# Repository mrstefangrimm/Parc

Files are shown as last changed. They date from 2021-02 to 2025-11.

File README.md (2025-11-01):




# Parc
Parc stand for Programmable Arduino Remote Control. This repository contains the software, the hardware and the mechanical design files.

| Parc (original) | Parc (PCB) |
| --- | --- |
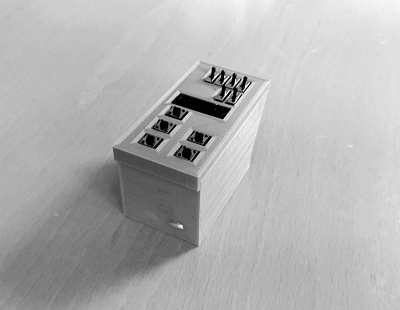
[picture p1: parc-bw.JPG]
Parc
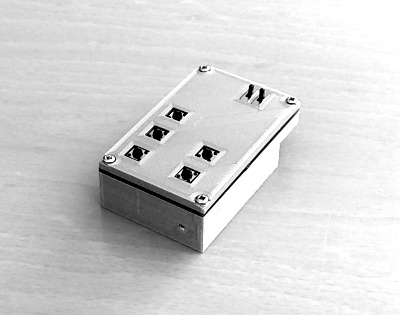
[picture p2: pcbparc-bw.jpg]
PCB Parc
|  |  |

## Motivation

One way to automated tasks on your PC is to write scripts. To run a script you have to be logged in to your PC already. If you write a script to lets say  sign in on a web application, it is not very save to put the password directly into the script.

Parc is a microcontroller based device that acts as a HID, these problems are solved.

## Getting Started

To use the software, you will have to build a Parc device. How to build one is described in an [instructable](https://www.instructables.com/Programmable-Arduino-Remote-Control/).

The software is very flexible and it is also possible to use it together with a breadboard or an Arduino UNO.

Minimal requirements to use the software on a breadboard:

- Arduino IDE
- Adafruit feather 32u4 BLE or Arduino UNO
- MCP23008
- Breadboard
- Push buttons and toggle switches

## Examples

A user manual and a programming guide can be found in the [Parc Wiki](https://github.com/mrstefangrimm/Parc/wiki).

## Tests

Unit tests cover the functionality of the domain model classes. All unit tests are part of the WinParcApp Visual Studio solution. Some test are can be executed with ArduinoUnit too.

Manual tests are defined in the [Test Specification](https://github.com/mrstefangrimm/Parc/blob/main/BuildVerificationTest-Specification.md).

## Software Toolchain

**Built Applications**

| Application | License |
| --- | --- |
| ParcApp | LGPL |
| PcbParcApp  | LGPL |
| UnoParcApp  | LGPL |
| WinParcApp  | LGPL |

**Used Libraries**

| Library | Licence |
| :--- | --- |
| ParcLib | LGPL |
| Adafruit MCP23017 Arduino Library | BSD |
| Adafruit BluefruitLE nRF51 | BSD |
| Arduino.h | LGPL |
| ArduinoUnit | MIT |
| StandardCplusplus | LGPL |
| TimerOne | CC BY 3.0 US |
| TemplateStateMachine | Apache License |
| .NET 4.8.1 | Microsoft license |

**Used Software Development Tools**

| Tool | License |
| --- | --- |
| Arduino IDE | GPL |
| Adafruit AVR Boards [Learn more](https://learn.adafruit.com/adafruit-feather-32u4-bluefruit-le/setup) | Adafruit license |
| avrdude | GPL |
| gcc | GPL |
| Visual Studio Community 2022 | Microsoft license |

## License

This is free software: you can redistribute it and/or modify it under the terms of the GNU Lesser General Public License as published by the Free Software Foundation, either version 3 of the License, or (at your option) any later version.

## Project History

The idea for the project came in mid January 2021 and was first published on instructables.com in mid April 2021.

## Change History

See [github releases](https://github.com/mrstefangrimm/Parc/releases).

<br />This work is licensed under a <a rel="license" href="http://creativecommons.org/licenses/by-sa/4.0/">Creative Commons Attribution-ShareAlike 4.0 International License</a>.

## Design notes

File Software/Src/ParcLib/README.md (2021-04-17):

# ParcLib

Arduino library which is part of the Parc software package. The library contains the domain model and shared code for 32u4 feathers. All Parc device projects are based on this library.

See also the [Parc Readme](https://github.com/mrstefangrimm/parc/) for a more detailed Readme.

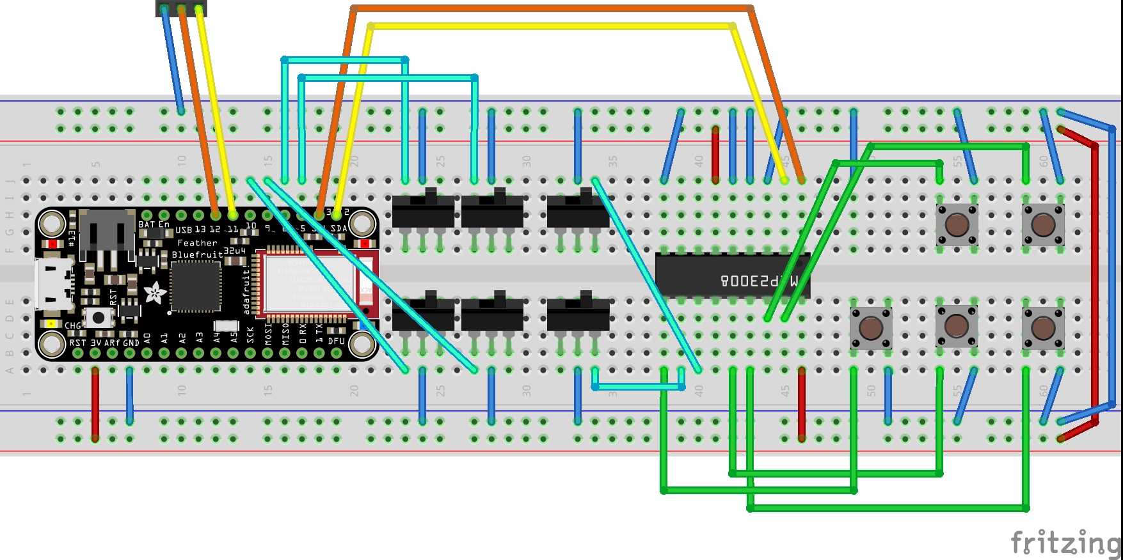
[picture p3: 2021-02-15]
Hardware/Fritzing/Breadboard-Parc.jpg

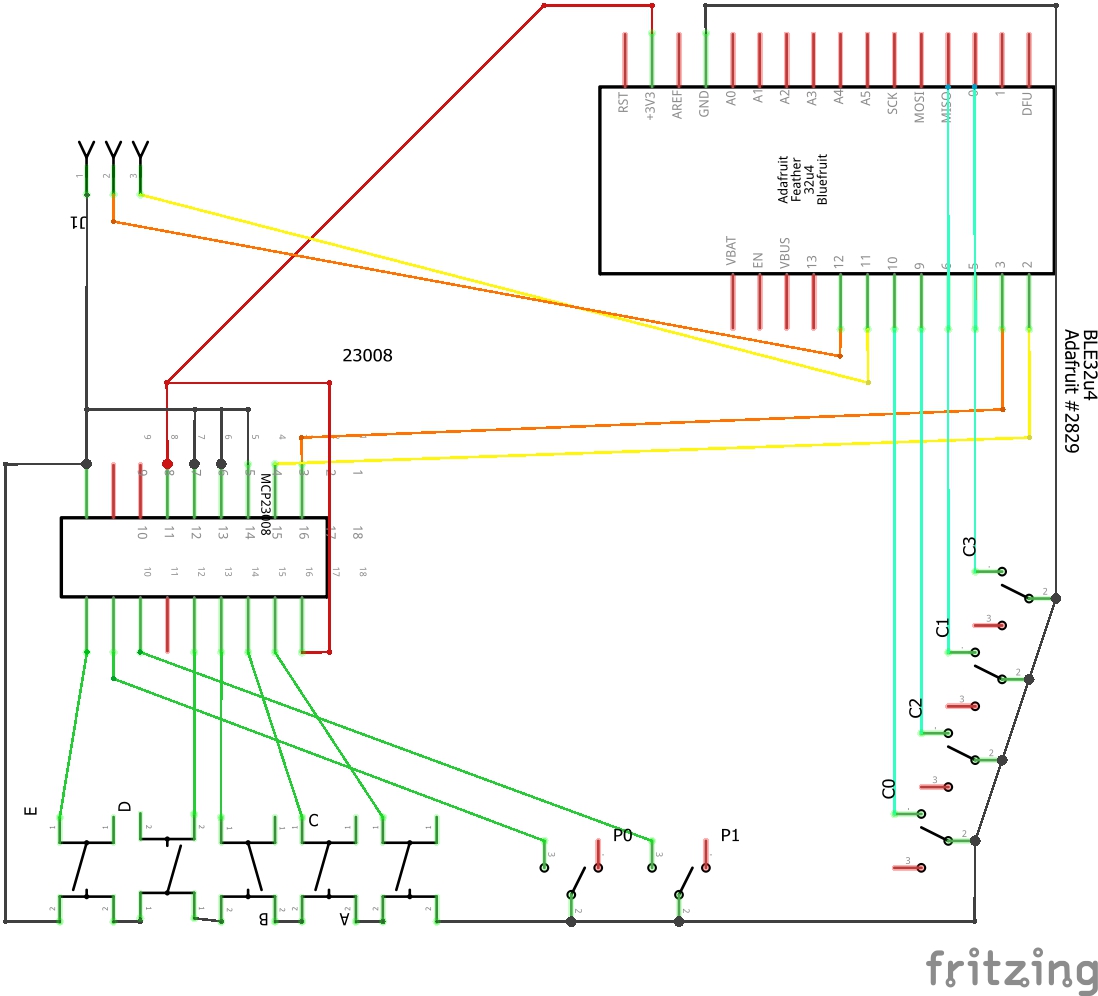
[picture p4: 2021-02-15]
Hardware/Fritzing/Schematic-Parc.jpg

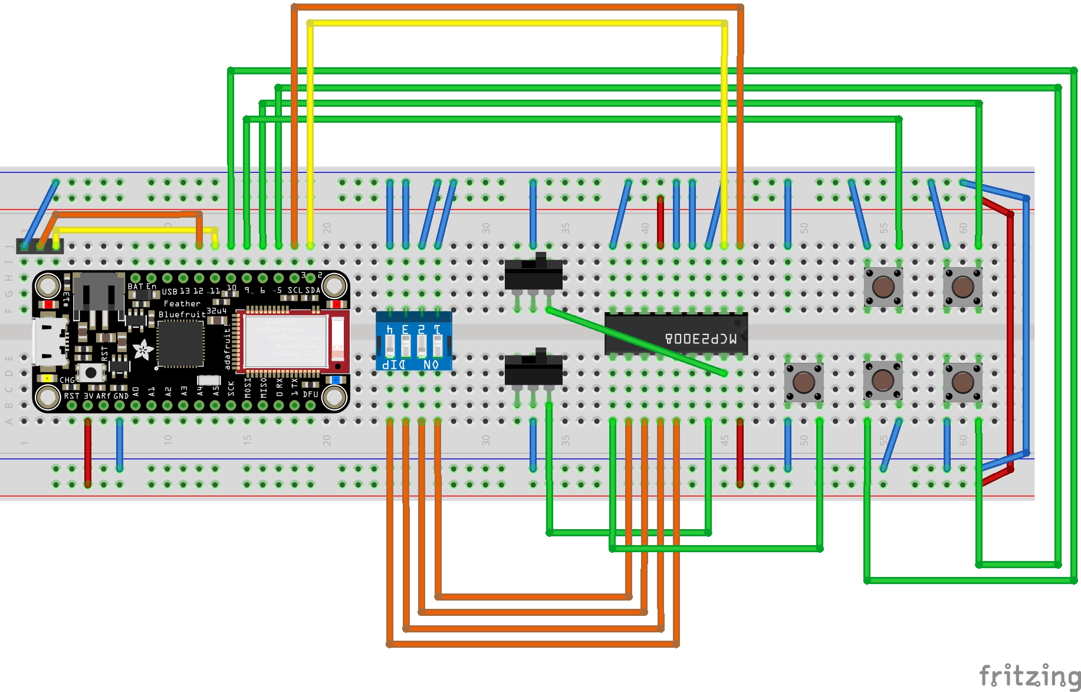
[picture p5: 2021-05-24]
Hardware/Fritzing/Breadboard-PcbParc.jpg

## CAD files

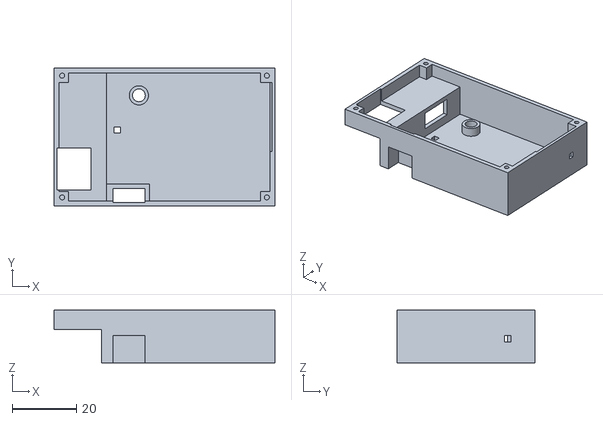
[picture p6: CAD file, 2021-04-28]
Instructable/STL-Models/PcbParc-Case.stl
69.0 x 43.0 x 16.5

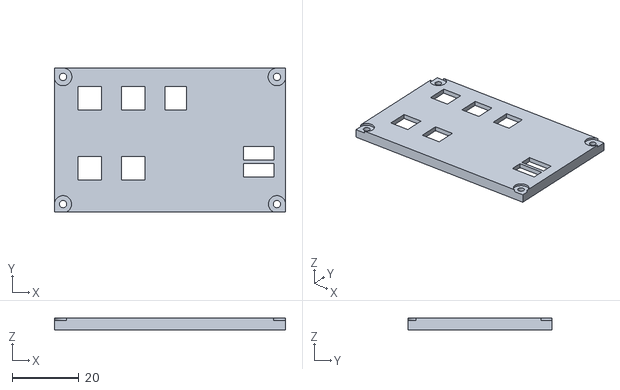
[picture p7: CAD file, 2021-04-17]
Instructable/STL-Models/PcbParc-Top.stl
69.0 x 43.0 x 3.50

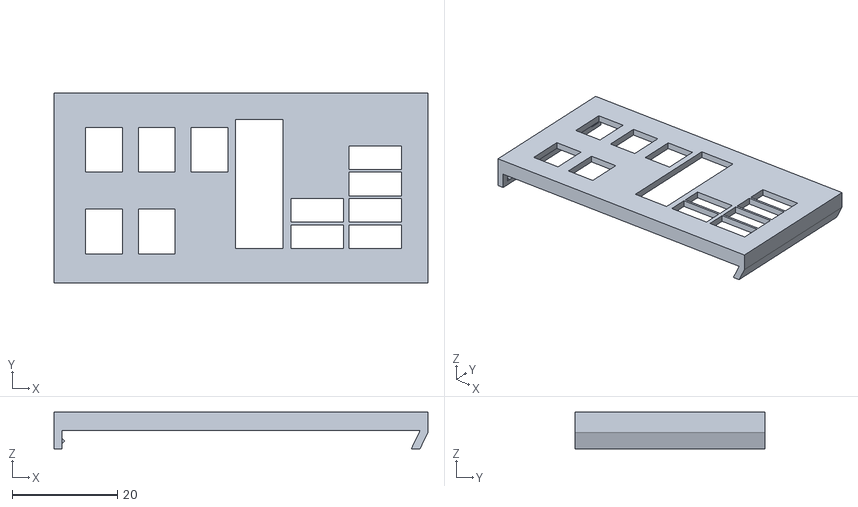
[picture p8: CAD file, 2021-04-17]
Instructable/STL-Models/Parc-Top.stl
71.0 x 36.0 x 7.00

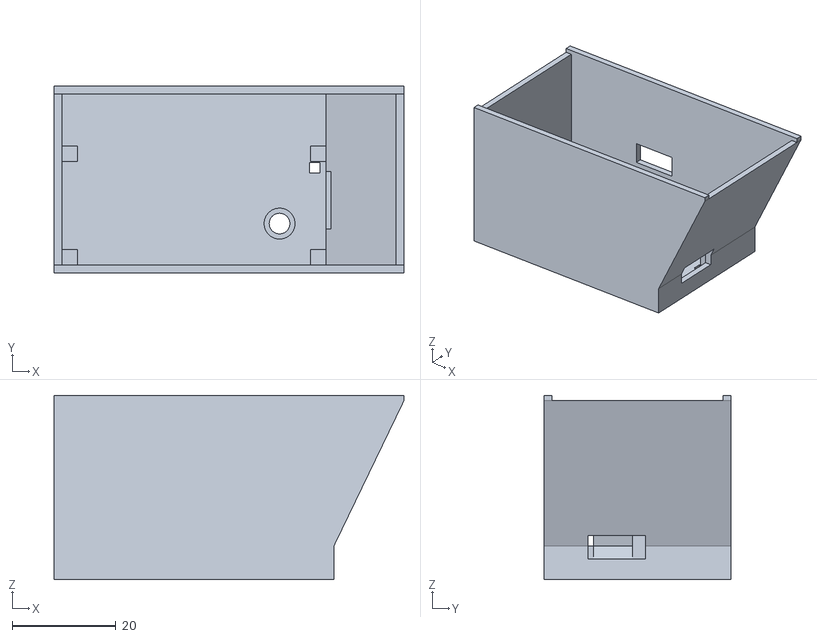
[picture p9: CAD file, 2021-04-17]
Instructable/STL-Models/Parc-Case.stl
67.5 x 36.0 x 35.5

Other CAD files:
MechanicalDesign/Sketchup/Parc-Case.skp
MechanicalDesign/Sketchup/Parc-Top.skp
MechanicalDesign/Sketchup/Parc-Total.skp
MechanicalDesign/Sketchup/PcbParc-Case.skp
MechanicalDesign/Sketchup/PcbParc-Shield.skp
MechanicalDesign/Sketchup/PcbParc-Top.skp

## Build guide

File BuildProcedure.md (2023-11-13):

# Parc Software Build Procedure

The build steps to build the Parc simulator and the PCB production files.

## 0. Preparation

Required software:

- Microsoft Visual Studio 2022
- Fitzing

Create a package folder.

## 1. Build Simulator

1. In Visual Studio, open 'WinParcApp.sln' from '\Software\Src\WinParcApp' with administrator rights.
2. Set 'WinParc.App' as startup project
3. Set the build configuration to 'Release' and 'x86'
4. Build the solution
5. Copy these file from the folder '\Software\Src\WinParcApp\Release' to a folder ' package\Software\Simulator':
   - WinParc.App.exe
   - WinParc.APIWrapper.dll
   - WinParcAPI.dll
   - WinParc.Core.dll
   - WinParc.View.exe

## 2. Create PCB Gerber files 

1. In Fritzing, open 'Keypad-v2.fzz'
2. Create folder 'Keypad-v2-Gerber'
3. File, Export, for Production, Extended Gerber (RS-274x)
4. Compress the folder to 'Keypad-v2-Gerber.zip'
5. Copy the files 'Keypad-v2.fzz' and 'Keypad-v2-Gerber.zip' to the folder 'package\Hardware'

## 3. Copy projects

1. Copy the 'ParcLib' folder from '\Software\Src' to the package folder
2. Copy the 'ParcApp' folder from '\Software\Src' to the package folder
3. Copy the 'PcbParcApp' folder from '\Software\Src' to the package folder
4. Copy the 'UnoParcApp' folder from '\Software\Src' to the package folder
5. In all folders form above, remove the file `PreBuild.bat`
6. In all the folders form above,  remove the links to the folders 'Core' and 'Feather' (don't forget the Test-folders in the ParcLib)

## 4. Create ParcLib Arduino library

1. Check the version in Software\ParcLib\library.properties
2.  Zip the folder ParcLib to ParcLib.zip (the root folder of ParcLib.zip is ParcLib; that is correct.)

## 5. Finalize the package

Package structure:

package_v0_0_1_0.zip/

	/Software/Simulator/*

	/Software/ParcLib.zip

	/Software/ParcApp/*

	/Software/PcbParcApp/*

	/Software/UnoParcApp/*

	/Hardware/Keypad-v2-Gerber.zip

	/Hardware/Keypad-v2.fzz

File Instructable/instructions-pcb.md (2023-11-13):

# Programmable Arduino Remote Control (PCB)

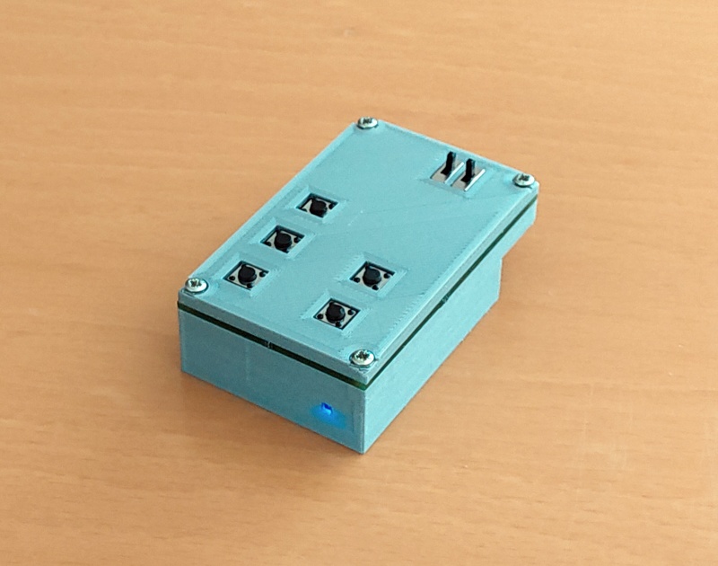
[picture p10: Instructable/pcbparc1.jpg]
parc1


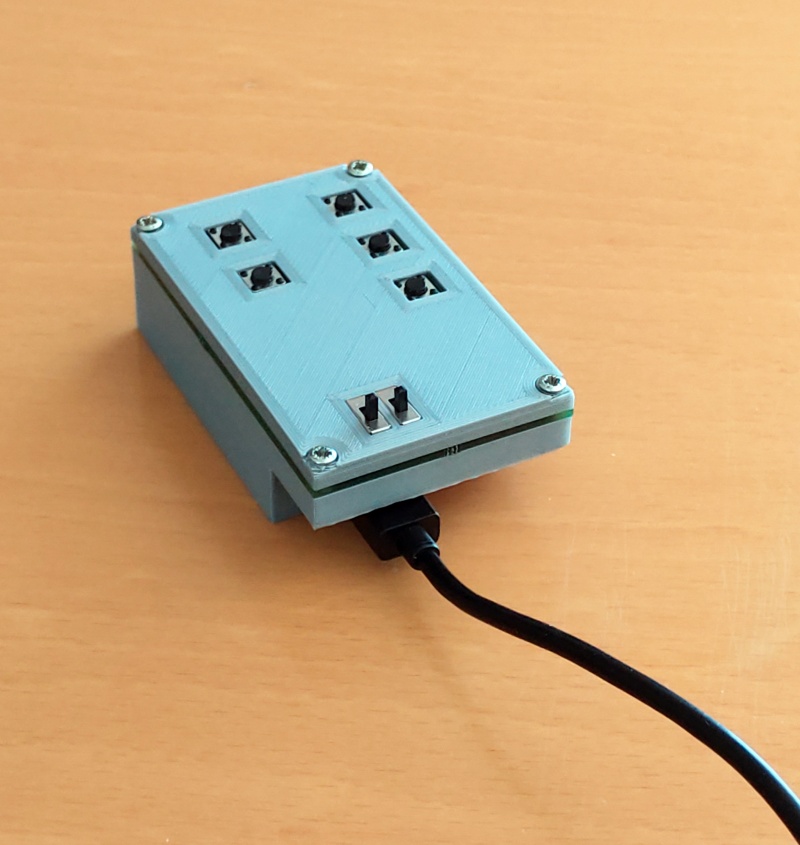
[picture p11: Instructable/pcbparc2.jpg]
parc2


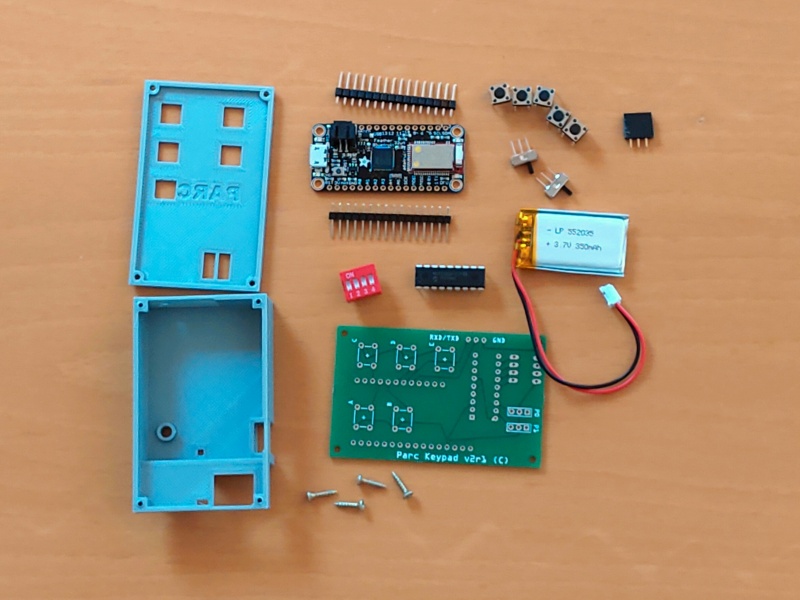
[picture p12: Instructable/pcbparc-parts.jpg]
parts


With this small, palm-sized device, it is possible to remote control your PC or your Smartphone. Or to control your PC and your Smartphone at the same time.

And it is freely programmable. You can write programs like: Login to  your PC, open and login to instructables.com, play/pause a movie or  adjust the volume on your Smartphone.

How is that possible? The used micro controller board has a chip that can act as a so called HID device, which stands for Human Interaction Device and simply means keyboard or mouse. And it has another chip, a Bluetooth chip which can act as a Bluetooth keyboard.

The programming is intuitive and there are more examples in the User Manual in the Wiki [1]. The syntax is described in the Programming Guide [1]. The video demonstrates a wireless login to a Windows PC with one click and a login to instructables.com with another click.

https://youtu.be/EJmvuccJp7M

What makes this remote control unique is that everything is stored in the volatile memory of the micro controller. It is safe to write programs which contain passwords.

And it is unique as Bluetooth remote control which you can program from a long list of possible commands. For more details see also the User Manual [1].

This is a improved version of the [Programmable Arduino Remote Control](https://www.instructables.com/Programmable-Arduino-Remote-Control/). It uses a printed circuit board (PCB) which you have to have manufactured. This costs a little extra. In return, the shape is more that of a remote control and it requires less soldering.

In this project, my goal  was to make a device that looks more like a remote control. Further, and because I use it every day, I wanted something more robust than its predecessor.

The direct material costs are approximately USD 78.

[1] [Parc Wiki on github](https://github.com/mrstefangrimm/Parc/wiki)

### Supplies:

1 Adafruit Feather 32u4 Ble ([at adafruit.com](https://www.adafruit.com/product/2829))

1 MicroUSB cable

1 Custom PCB (see step Printed Circuit Board)

1 IC MCP23008 (https://www.adafruit.com/product/593)

1 LiPo 350 mAh (https://www.adafruit.com/product/2750)

5 Button switch, 6mm (https://www.adafruit.com/product/1119)

2 Slide switch (https://www.adafruit.com/product/805)

1 Stack female headers (https://www.adafruit.com/product/2886)

1 DIP switch 4 positions ([at mouser](https://www.mouser.com/ProductDetail/E-Switch/KAS1104ET?qs=f57gQzlyLioBdQLVanmY3g%3D%3D))

4 Screw M2 x l10

1 Windows PC

1 Arduino IDE (https://www.arduino.cc/en/software). Optional: PuTTY (https://www.putty.org)

1 3D Printer

1 Soldering iron and soldering wire

21g PLA filament

I added links to the Adafruit and the Mouser web shops, but you also get the parts elsewhere. For example for the LiPo battery, search for "PKCELL LP552035".

## Step 1: 3D printed parts

PLA and the standard settings (20% infill) can be used. Support structures have to be enabled.

- PcbParc-Case.stl

- PcbParc-Top.stl

## Step 2: Printed Circuit Board

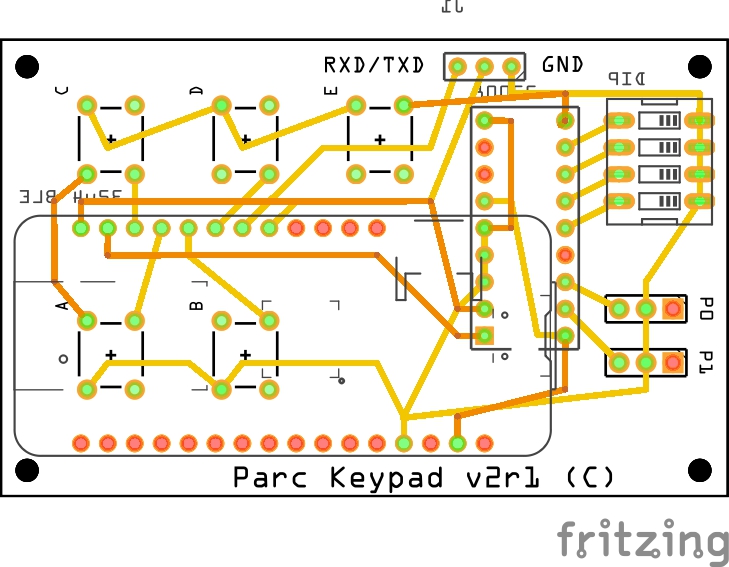
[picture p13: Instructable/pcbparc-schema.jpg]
PCB Schema


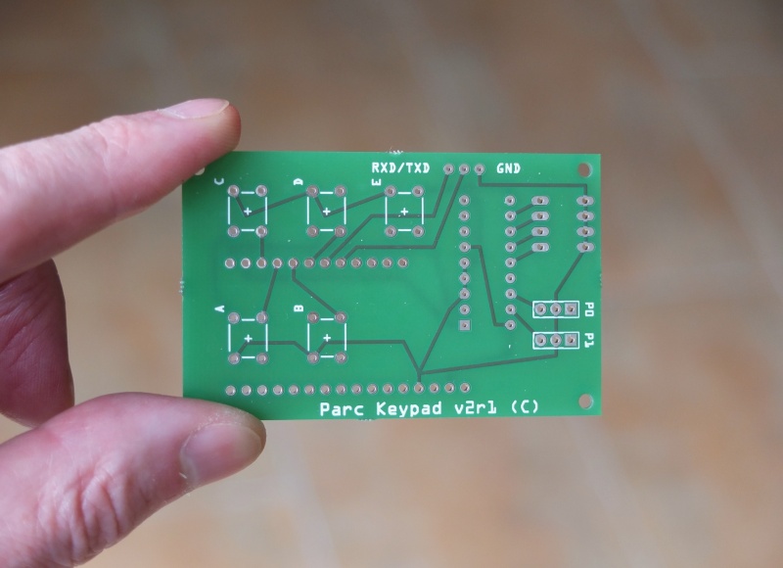
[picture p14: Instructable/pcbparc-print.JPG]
PCB Print


I had mine produced by Aisler (https://aisler.net/). At Aisler, it is possible to produce the PCB directly from the attached Fritzing project file.

If the manufacturer of your choice does not support Fritzing as import format, then try the [Gerber files](https://github.com/mrstefangrimm/Parc/blob/main/Instructable/Keypad-v2-Gerber.zip). "All" manufacturer support Gerbers.

## Step 3: Soldering keypad

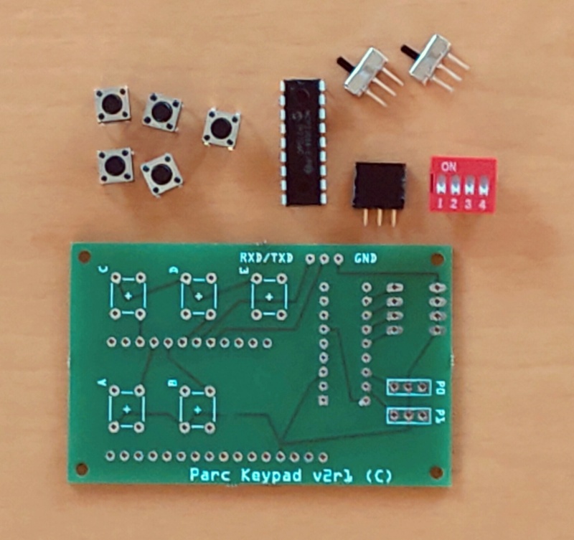
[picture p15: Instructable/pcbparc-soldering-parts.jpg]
soldering parts


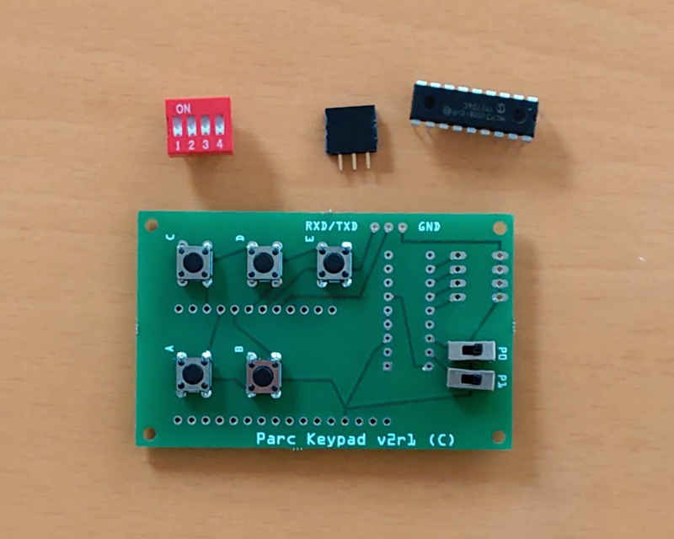
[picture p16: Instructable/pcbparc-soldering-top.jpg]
soldering keypad-top


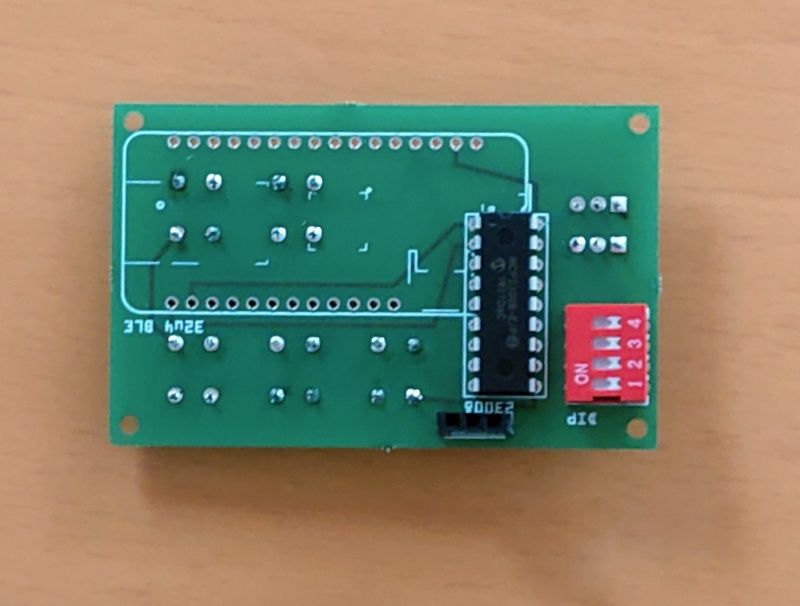
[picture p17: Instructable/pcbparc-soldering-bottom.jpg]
soldering keypad-bottom


Solder the five push buttons and the two slide switches to the front side of the PCB. Turn the PCB and add the MCP23008. Make sure the direction of the IC is correct.

Add the DIP switch.

From a female header stack, break out a piece of three pin sockets. Solder this piece to the back side of the PCB. 

## Step 4: Soldering micro controller

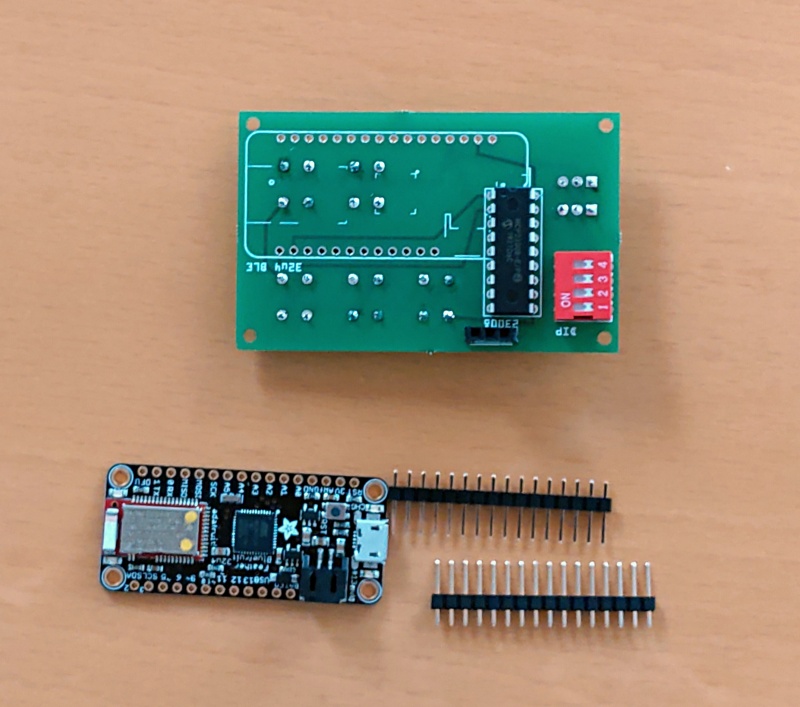
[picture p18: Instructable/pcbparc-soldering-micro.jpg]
soldering keypad-bottom


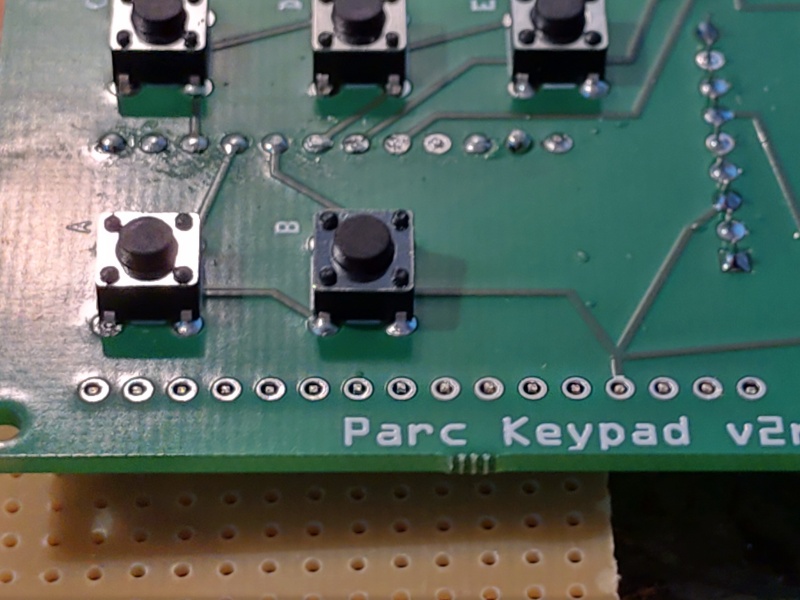
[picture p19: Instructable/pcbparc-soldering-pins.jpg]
soldering keypad-microcontroller


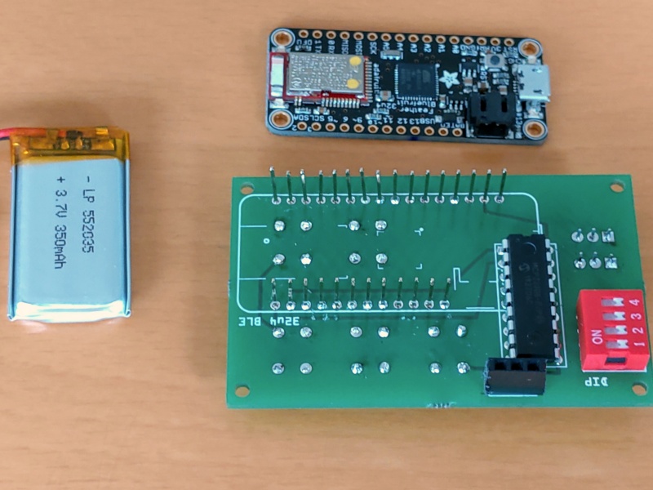
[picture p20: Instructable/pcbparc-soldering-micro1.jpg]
soldering keypad-microcontroller


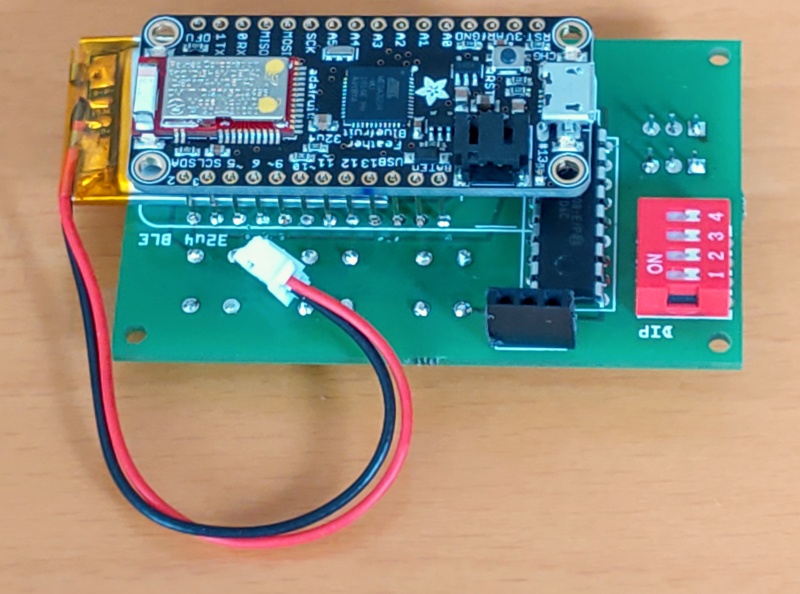
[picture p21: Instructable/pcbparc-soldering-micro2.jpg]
soldering keypad-microcontroller


Solder the header pins to the back side of the keypad. You can also solder the pins first to the micro controller board and as the second solder it to the keypad.

Solder the pins flush to the keypad. The plastic distance holder that holds the pins as an array is by default set that the pins look out 1 mm. So you have to push the pins 1 mm down first.

After the pins are soldered to the keypad, remove the black distance holder band. The battery will required all the space in between the two components.

Lastly, add the micro controller board. The battery shall be free movable between the two components.

## Step 5: Assemble

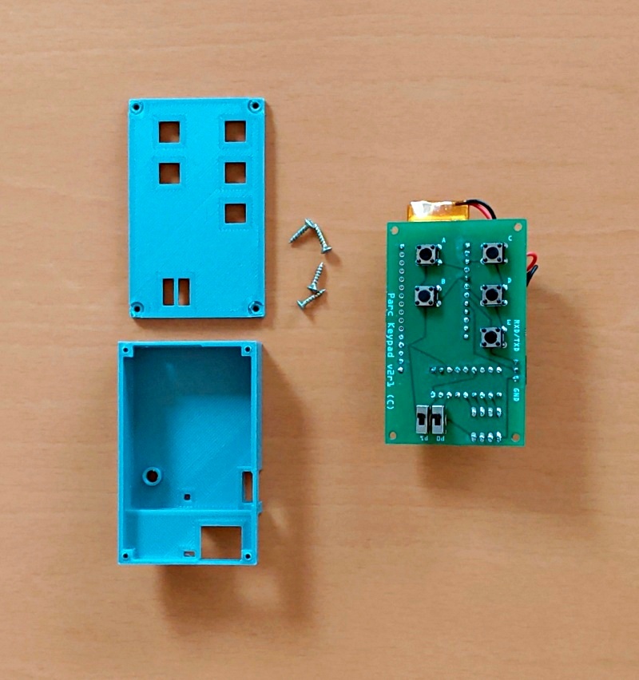
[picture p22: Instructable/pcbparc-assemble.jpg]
assemble


Connect the battery to the micro controller board. Now you can put whole assembly into the case and use it.

That was it basically. Next you will learn how to install the software and program the remote control.

## Step 6: Arduino IDE, libraries and boards

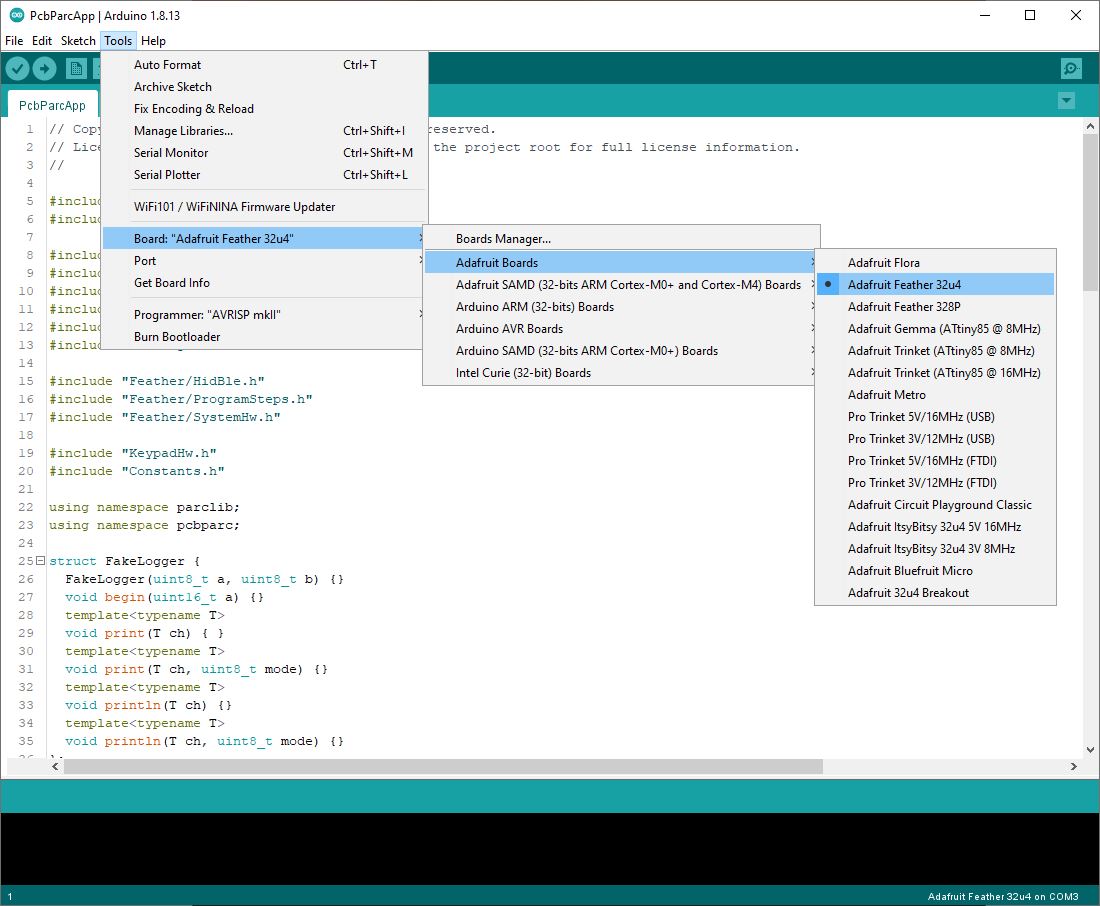
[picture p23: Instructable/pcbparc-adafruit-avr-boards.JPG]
Adafruit Boards


For the following steps, the [Arduino IDE](https://www.arduino.cc/en/software) is required. Download and install the IDE.

Follow the steps from Adafruit and install the "Adafruit AVR Boards" board package. Adafruit has always great [step-by-step instructions](https://learn.adafruit.com/adafruit-feather-32u4-bluefruit-le/setup).

In the Arduino IDE library manager, install the libraries "Adafruit MCP23008 library" and "TimerOne".

Download the  [Template State Machine library](https://github.com/mrstefangrimm/TemplateStateMachine/releases) and [import the .zip file](https://docs.arduino.cc/software/ide-v1/tutorials/installing-libraries#importing-a-zip-library) in the Arduino IDE.

Download the latestes [packages_v0.1.x.x.zip version from releases](https://github.com/mrstefangrimm/Parc/releases). Unzip the package folder and [import the Parclib.zip](https://docs.arduino.cc/software/ide-v1/tutorials/installing-libraries#importing-a-zip-library) in the Arduino IDE.

Copy PcbParcApp in the package folder into your project folder and open the PcbParcApp.ino in the  Arduino IDE.

Attach the PCB Parc remote control to your PC with the USB cable. In the  IDE, select the board "Adafruit Feather 32u4" and select the COM port with the same label.

If compiling and uploading succeeds, your device is ready for use.

## Step 7: Test software

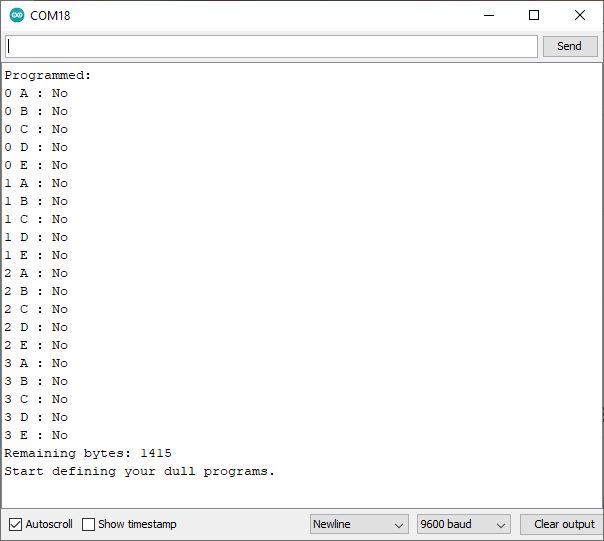
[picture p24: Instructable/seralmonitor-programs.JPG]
Serial Monitor


Open the PcbParcApp.ino in the Arduino IDE. Compile and upload the software.

In the Arduino IDE, open the Serial Monitor. In the input field, type in a question mark ("?") and hit "Send". As you haven't programmed your device yet, all program slots are empty.

Here's your first program. In the input field of the Serial Monitor, type in: "{ 0 B: UK <Win> 'l'; }" and press "Send". The left lower button on the keypad will now lock the Windows screen when pressed.

## Step 8: Program

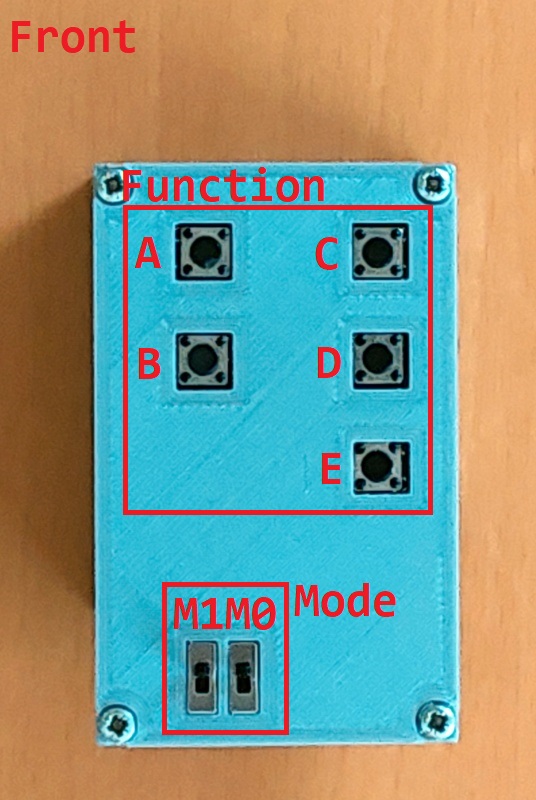
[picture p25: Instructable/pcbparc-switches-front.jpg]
Parc keypad


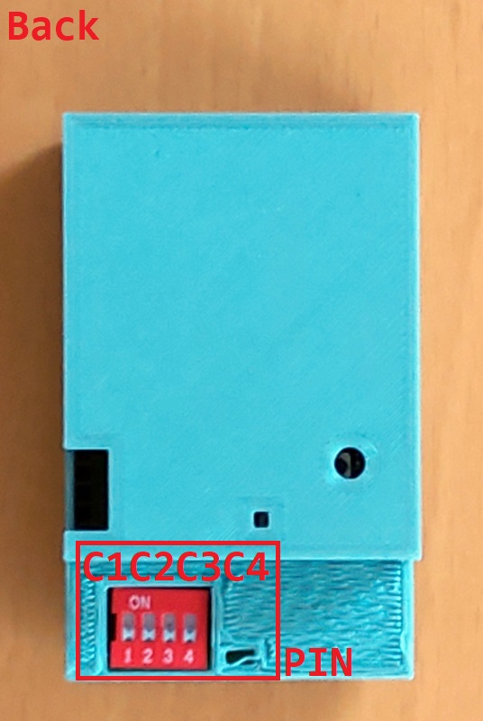
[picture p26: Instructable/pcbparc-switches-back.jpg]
Parc keypad


It is time to code. To give you an idea, I describe some of the programs used in the demo videos linked in the introduction section. For More information, please have a look at the User Manual in the [Wiki](https://github.com/mrstefangrimm/Parc/wiki).

Login Commands:

`{ 1 A: BK <Ctrl> <Alt> <Del>; W 2000; BT password; W 1000; BK <Enter>; }`

- "1 A" defines the key and mode the program is for. "1" is mode 1 which is  set with the slide switch M0. "A" is the upper left button
- `BK <Ctrl> <Alt> <Del>` sends a "Del" keypress with the control keys "Ctrl" and "Alt"
- "W 2000" lets the program wait for 2 seconds. The program waits for the Windows login screen before it writes the password
- "BT password" sends keypresses "p", "a", "s", ... . Note that it assumes a US-English keyboard. If you have keyboard settings for a different keyboard, there is a simple trick: Send `BK <Win> <Space>` as the first program step. This will change the keyboard on the PC.

Remote Control Commands:

```{ 3 A: BC PlayPause; }
{ 3 B: BC MediaNext; }
{ 3 C: BC Volume+; }
{ 3 D: BC Volume-; }
{ 3 E: BC Mute 1000; }
```

- "3 A" defines the program for mode 3 and key "A". Mode 3 is set with the slide switches "M1" and "M0"
- "BC" stands for Bluetooth Controlkey. This sends commands that most Bluetooth connected devices "understand"
- "BC Mute 1000". Sends Mute and waits for 1 second. This seconds hinders the device to interpret you key press as two keypresses

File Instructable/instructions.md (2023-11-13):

# Programmable Arduino Remote Control

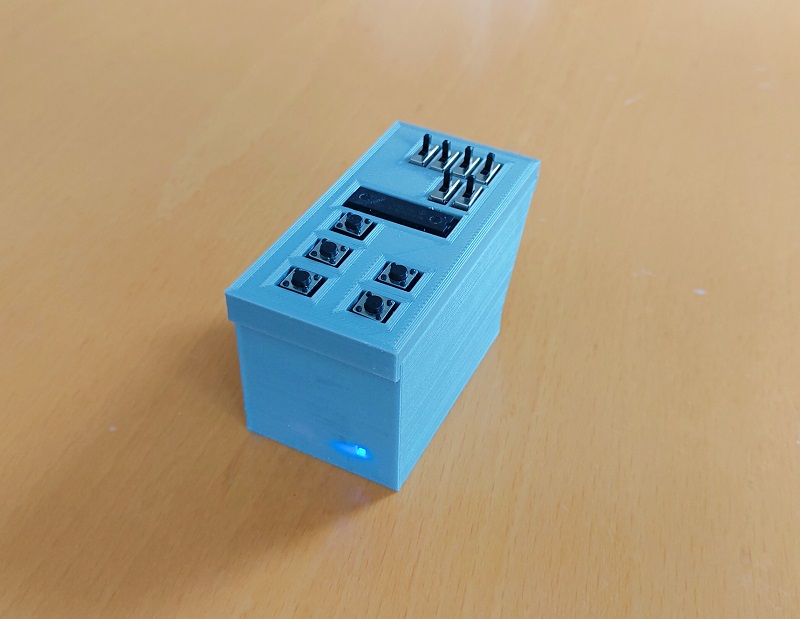
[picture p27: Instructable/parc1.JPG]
parc1


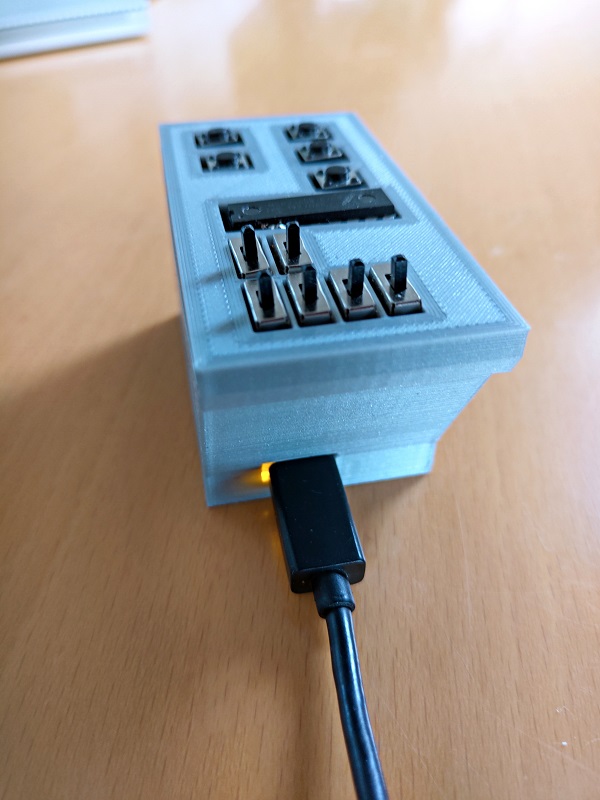
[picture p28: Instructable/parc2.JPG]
parc2


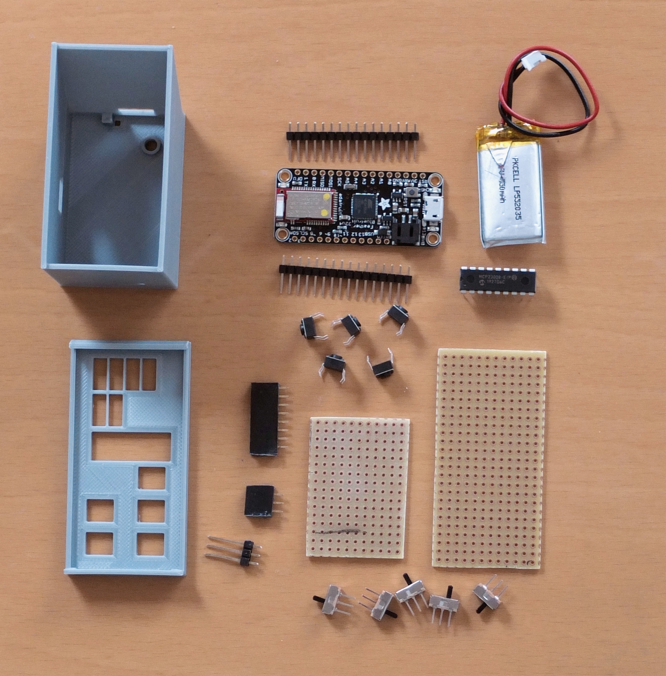
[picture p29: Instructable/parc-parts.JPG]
parts


With this small, palm-sized device, it is possible to remote control your PC or your Smartphone. Or to control your PC and your Smartphone at the same time.

And it is freely programmable. You can write programs like: Login to  your PC, open and login to instructables.com, play/pause a movie or  adjust the volume on your Smartphone.

How is that possible? The used micro controller board has a chip that can act as a so called HID device, which stands for Human Interaction Device and simply means keyboard or mouse. And it has another chip, a Bluetooth chip which can act as a Bluetooth keyboard.

The programming is intuitive and there are more examples in the User Manual in the Wiki [1]. The syntax is described in the Programming Guide [1]. The video demonstrates a wireless login to a Windows PC with one click and a login to instructables.com with another click.

[Login Demo](https://youtu.be/DcMdJxYA3Bc)

In the second video, the Parc device is used as a Bluetooth remote control with the functions: Volume Up and Down, Next Song, Mute. Further, the remote control is connected to the PC and sends keyboard commands that open a text editor and type in some text.

[Dual Use Demo](https://youtu.be/E0nmfwVdOjc)

What makes the Parc remote control unique is that everything is stored in the volatile memory of the micro controller. It is safe to write programs which contain passwords.

And it is unique as Bluetooth remote control which you can program from a long list of possible commands. For more details see also the User Manual [1].

The idea for the Parc remote control came when I read and made this great instructable:

https://www.instructables.com/How-to-Make-a-Arduino-HID-Keyboard

It describes how you can turn an Arduino UNO into a USB keyboard. The Arduino UNO is limited in the way that the firmware on the serial interface chip has to be changed. But read yourself.

From the first prototype with hardcoded programs to the current version, I use the Parc remote control almost every day. At work it is handy to login, lock the screen or login to the time management tool. At home I often use it as remote control when I watch a movie on my PC.

The direct material costs are approximately USD 70.

[1] Parc Wiki: https://github.com/mrstefangrimm/Parc/wiki

### Supplies:

1 Adafruit Feather 32u4 Ble (https://www.adafruit.com/product/2829)

1 MicroUSB cable

1 IC MCP23008 (https://www.adafruit.com/product/593)

1 LiPo 350 mAh (https://www.adafruit.com/product/2750)

5 Button switch, 6mm (https://www.adafruit.com/product/1119)

6 Slide switch (https://www.adafruit.com/product/805)

1 Prototyping board, cut into 2 pieces, 32x65mm and 32x42mm  (https://www.adafruit.com/product/2670)

1 Stack female headers (https://www.adafruit.com/product/2886)

1 Long male header pins (https://www.adafruit.com/product/400) 

1 Windows PC

1 Arduino IDE (https://www.arduino.cc/en/software). Optional: PuTTY (https://www.putty.org)

1 3D Printer

1 Soldering iron and soldering wire, hookup wire

21g PLA filament

1 Metal saw (to cut the prototyping board)

I added links to the Adafruit webshop, but you also get the parts elsewhere. For the LiPo battery, search for "PKCELL LP552035".

## Step 1: 3D printed parts

PLA and the standard settings (20% infill) can be used. Enable support structures for the openings for the USB plug.

- Parc-Case.stl

- Parc-Top.stl

## Step 2: Prototype on breadboard

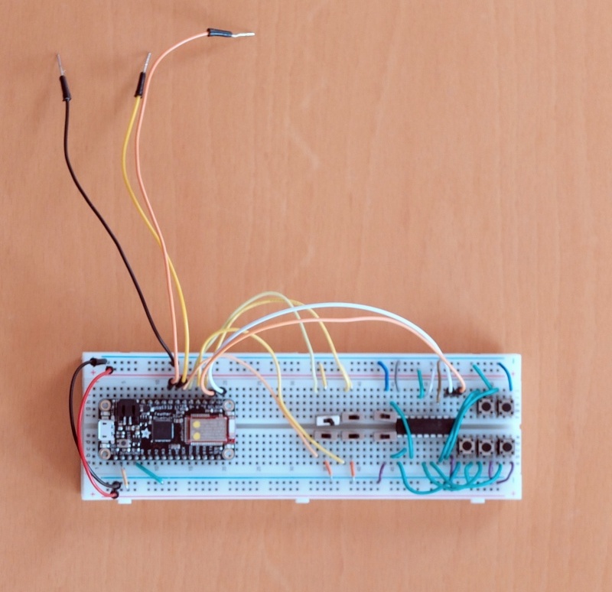
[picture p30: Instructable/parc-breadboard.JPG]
breadboard


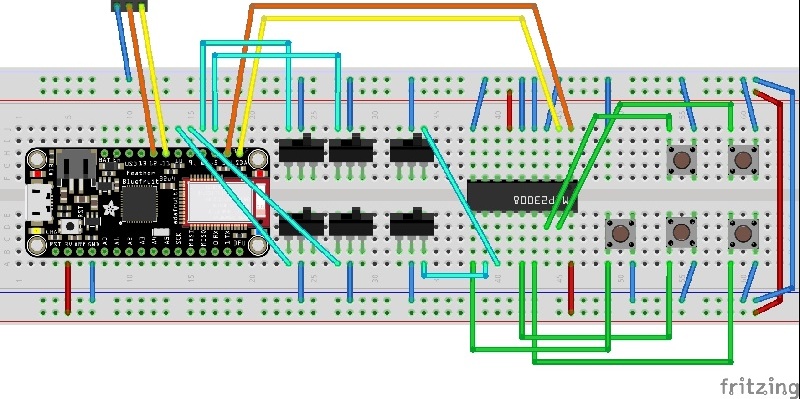
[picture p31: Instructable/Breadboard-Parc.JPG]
breadboard-schema


Once you have all the parts, I recommend to test the parts on the breadboard before you start building the remote control. The wiring on the pictures is the same as for the final product. 

I recommend to install the test program first and check that the wiring is correct and the component work. Steps 6 and 7 describes how this is done.

If you like, you can attach the battery, install the final software and  use breadboard as remote control. If are not planning to actually build the  device, continue with step 6.

## Step 3: Soldering keypad

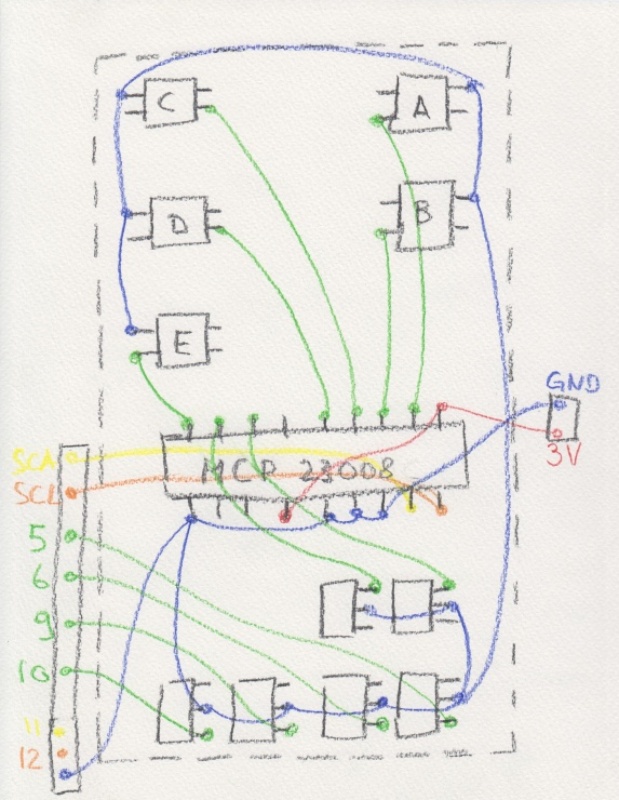
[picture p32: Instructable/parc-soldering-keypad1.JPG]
soldering keypad


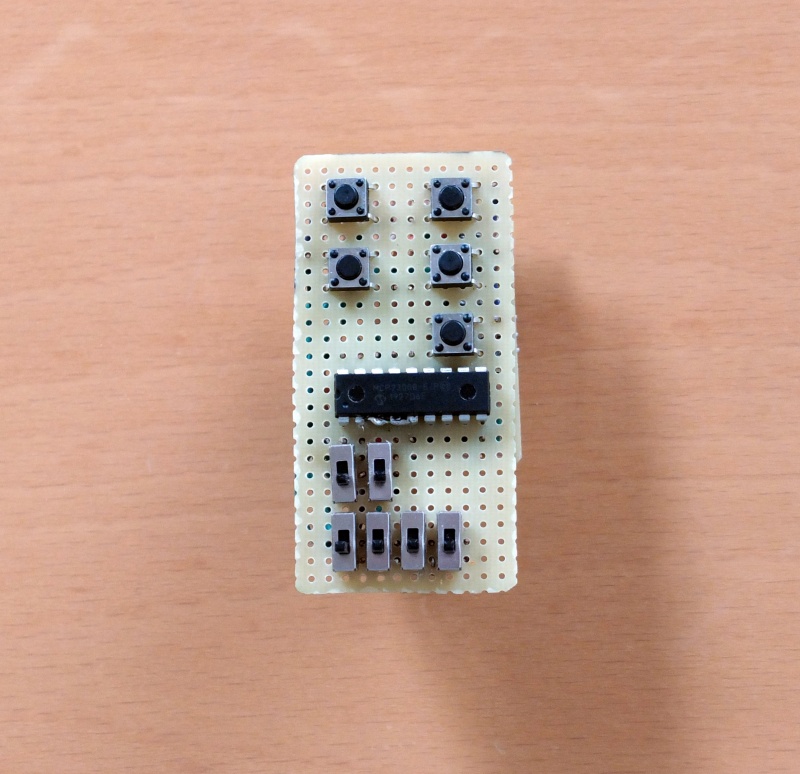
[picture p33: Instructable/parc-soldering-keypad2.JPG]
soldering keypad


This will be the most time consuming part. Take your time. The prototyping board has the dimension 32x65mm, or 25x12 holes.

The hand painted soldering plan should help you through the process. Leave the length of the wires that are lead out approximately 40mm long. These wires are soldered to the connection board in the next step. The wires are labeled: 3V, GND, SDA, SCL, 5, 6, 8, 10.

Add the switches and the MCP23008 first and then start with the wires for the power (red on the painting). Then add the wires for the ground (blue) and then the green wires. 

## Step 4: Soldering connection board

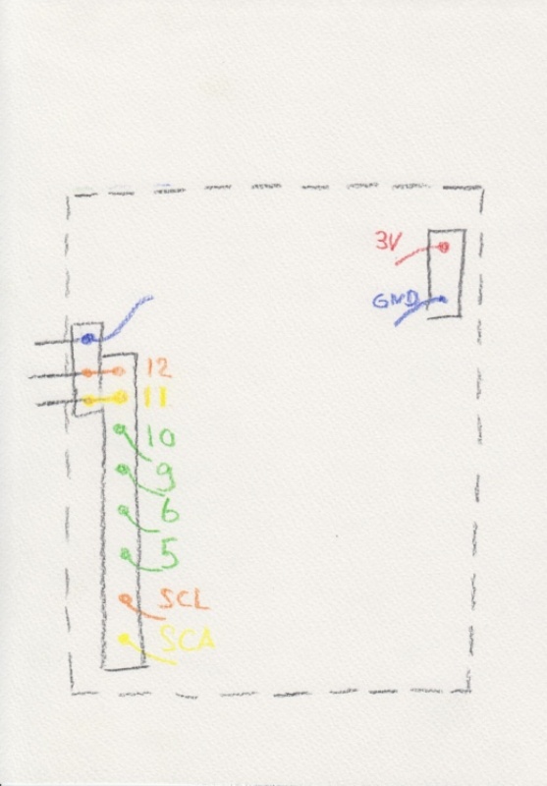
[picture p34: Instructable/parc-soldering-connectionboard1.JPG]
soldering-connectionboard


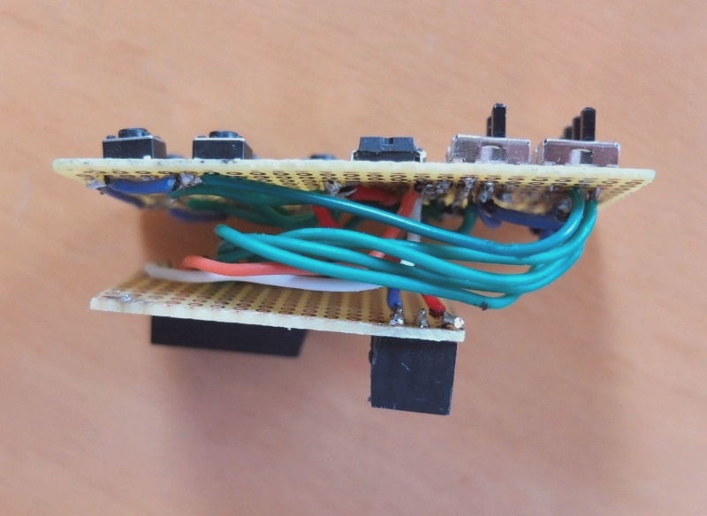
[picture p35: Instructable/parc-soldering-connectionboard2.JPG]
soldering-connectionboard


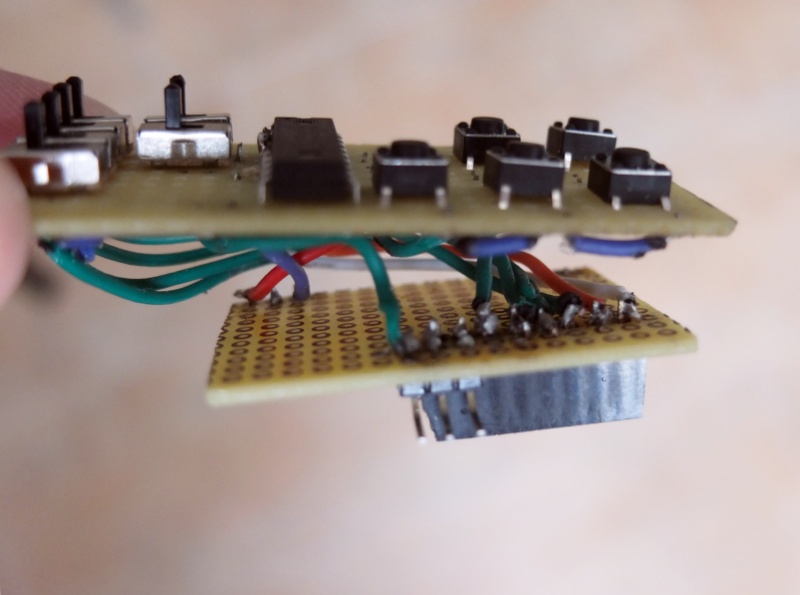
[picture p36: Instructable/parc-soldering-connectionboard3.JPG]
soldering-connectionboard


The connection board's size is 32x42mm, or 16x12 holes. 

Add (solder) the stack headers to the board first. One has 8 pin sockets and one has 3 pin sockets. 

Add an array of 3 long male pins to the connection board. First you bend the pins in a 90 degree angle. The center and the right pin (see photo) are connected to the two most left stack header pins. 

Cut the lead out wires of the keypad board to the right length. The distance between the keypad and the connection board should be approximately 12mm. Hold the boards together and bend the wires into the correct form.

## Step 5: Assemble

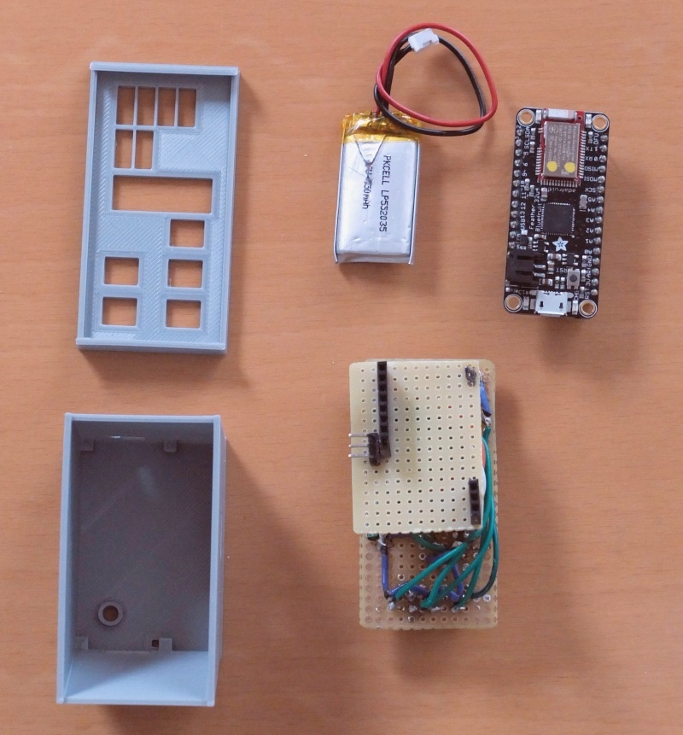
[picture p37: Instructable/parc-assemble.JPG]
assemble


You're almost through. Plug-in the micro controller board into the stack headers of the connection board. The 3V3 and the GND pin of the micro controller board go into the 3-holes stack header. The pins SDA to 12 of the micro controller board go into the other stack header.

The battery is stashed between the micro controller and the connection board. Now you can put it into the case and use it.

## Step 6: Arduino IDE, libraries and boards

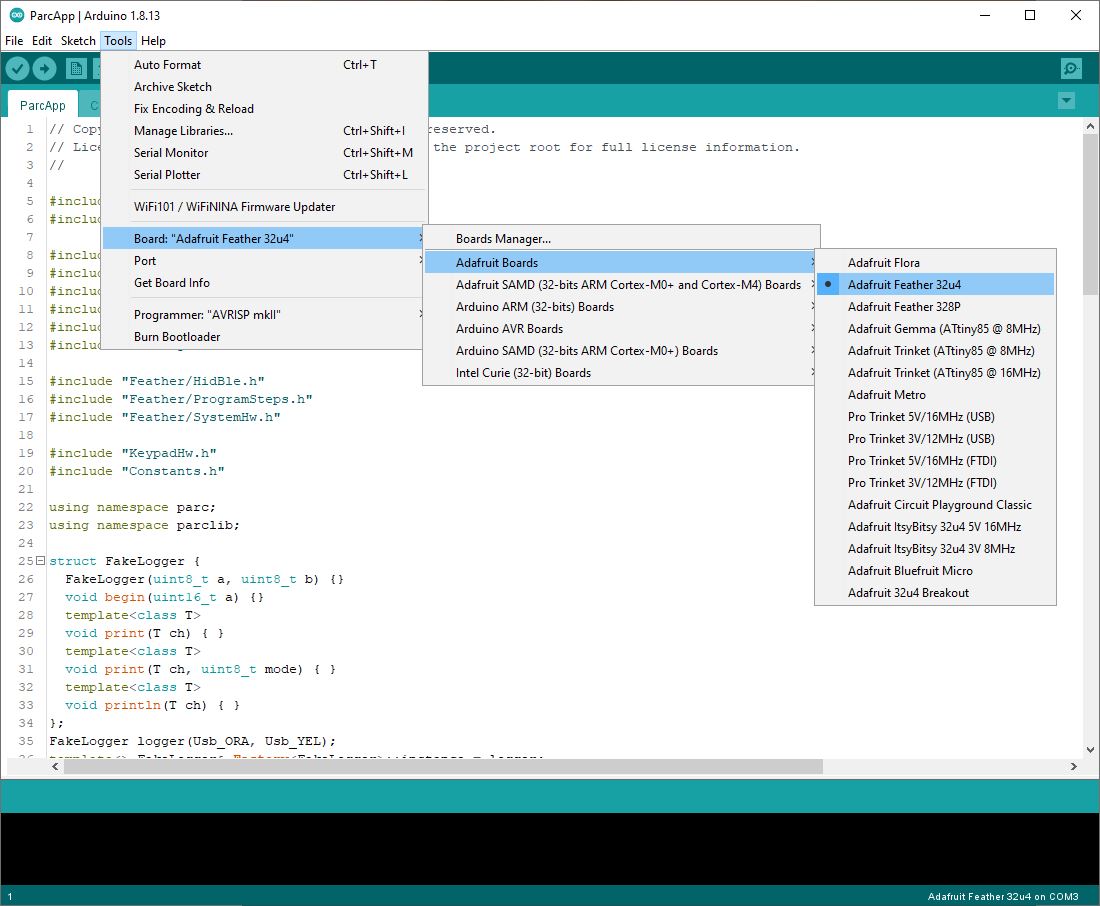
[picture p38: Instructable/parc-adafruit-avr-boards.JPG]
"Adafruit Boards"


For the following steps, the [Arduino IDE](https://www.arduino.cc/en/software) is required. Download and install the IDE.

Follow the steps from Adafruit and install the "Adafruit AVR Boards" board package. Adafruit has always great [step-by-step instructions](https://learn.adafruit.com/adafruit-feather-32u4-bluefruit-le/setup).

In the Arduino IDE library manager, install the libraries "Adafruit MCP23008 library" and "TimerOne".

Download the  [Template State Machine library](https://github.com/mrstefangrimm/TemplateStateMachine/releases) and [import the .zip file](https://docs.arduino.cc/software/ide-v1/tutorials/installing-libraries#importing-a-zip-library) in the Arduino IDE.

Download the latestes [packages_v0.1.x.x.zip version from releases](https://github.com/mrstefangrimm/Parc/releases). Unzip the package folder and [import the Parclib.zip](https://docs.arduino.cc/software/ide-v1/tutorials/installing-libraries#importing-a-zip-library) in the Arduino IDE.

Copy ParcApp in package folder into your project folder and open the ParcApp.ino in the  Arduino IDE.

Attach the Parc remote control to your PC with the USB cable. In the  IDE, select the board "Adafruit Feather 32u4" and select the COM port with the same label.

If compiling and uploading succeeds, your device is ready for use.

## Step 7: Hardware test

[Test](https://youtu.be/5a9cY7EyVzM)

It is time to test your work. Download the KeypadTest.ino and open it the Arduino IDE. Compile and upload it.

In the Arduino IDE, open the Serial Monitor. If you press one of the push buttons or use one of the slide switches on the keypad you should see it on the Serial Monitor.

## Step 8: Software test

Serial Monitor

Open the ParcApp.ino in the Arduino IDE. Compile and upload it.

In the Arduino IDE, open the Serial Monitor. In the input field, type in a question mark ("?") and hit "Send". As you haven't programmed your device yet, all program slots are empty.

Here's your first program. In the input field of the Serial Monitor, type in: "{ 0 B: UK <Win> 'l'; }" and press "Send". The left lower button on the keypad will lock the Windows screen.

## Step 9: Program

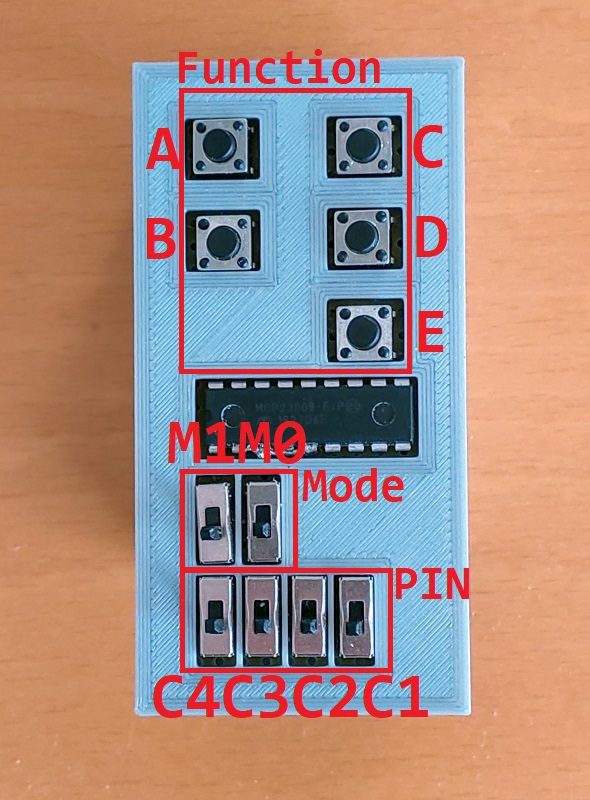
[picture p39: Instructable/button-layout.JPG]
Parc keypad


It is time to code. To give you an idea, I describe some of the programs used in the demo videos linked in the introduction section. For More information, please have a look at the User Manual in the [Wiki](https://github.com/mrstefangrimm/Parc/wiki).

Login Commands:

`{ 1 A: BK <Ctrl> <Alt> <Del>; W 2000; BT password; W 1000; BK <Enter>; }`

- "1 A" defines the key and mode the program is for. "1" is mode 1 which is  set with the slide switch M0. "A" is the upper left button
- `BK <Ctrl> <Alt> <Del>` sends a "Del" keypress with the control keys "Ctrl" and "Alt"
- "W 2000" lets the program wait for 2 seconds. The program waits for the Windows login screen before it writes the password
- "BT password" sends keypresses "p", "a", "s", ... . Note that it assumes a US-English keyboard. If you have keyboard settings for a different keyboard, there is a simple trick: Send `BK <Win> <Space>` as the first program step. This will change the keyboard on the PC.

Remote Control Commands:

```{ 3 A: BC PlayPause; }
{ 3 B: BC MediaNext; }
{ 3 C: BC Volume+; }
{ 3 D: BC Volume-; }
{ 3 E: BC Mute 1000; }
```

- "3 A" defines the program for mode 3 and key "A". Mode 3 is set with the slide switches "M1" and "M0"
- "BC" stands for Bluetooth Controlkey. This sends commands that most Bluetooth connected devices "understand"
- "BC Mute 1000". Sends Mute and waits for 1 second. This seconds hinders the device to interpret you key press as two keypresses

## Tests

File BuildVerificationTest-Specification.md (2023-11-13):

# Parc Build Verification Test Specification

Manual test steps to test the firmware on the devices.  Unit tests and automated tests are not part of this verification test. It is expected that these tests passed.

## 0. Preparation

Required software:

- Arduino IDE
- Second terminal emulator such as YAT or PuTTY
- Atmel Flip
- build package with the simulator binaries
- ParcLib installed

Required PARC devices and Hardware:

- PARC
- PCB PARC
- UNO PARC
- Debug cable
- USB cable

## 1. Unit Tests

1. Connect the PC to the PARC device or Arduino UNO, USB cable
1. In the Arduino IDE, open the sketch in \Documents\Arduino\libraries\ParcLib\Tests\Core\BitCounterTest.
1. Upload the firmware and open the Serial Monitor
   - All tests pass
1. Repeat test steps 2 and 3 for
   - \Documents\Arduino\libraries\ParcLib\Tests\Core\HidAoTest
   - \Documents\Arduino\libraries\ParcLib\Tests\Core\KeypadAoTest
   - \Documents\Arduino\libraries\ParcLib\Tests\Core\StringParcTest
   - \Documents\Arduino\libraries\ParcLib\Tests\Core\SystemMonitorAoTest
   - \Documents\Arduino\libraries\ParcLib\Tests\Core\TerminalAoTest\TerminalAoCommandsTest
   - \Documents\Arduino\libraries\ParcLib\Tests\Core\TerminalAoTest\TerminalAoVariousTest
   - \Documents\Arduino\libraries\ParcLib\Tests\Core\ValueQueueTest
   - \Documents\Arduino\libraries\ParcLib\Tests\Feather\ProgramTest

## 2. Test PARC

5. Connect the PC to the PARC device, USB and Debug cable
1. In the Arduino IDE, open the project \Software\Src\ParcApp\ParcApp.ino 
1. Enable the logging by changing the logging from `FakeLogger`to `SoftwareSerial`
1. Upload the firmware
1. Reset the device by pressing the reset button
   - the used pins and the modes are logged on the debug output
1. In the Arduino IDE, open the Serial Monitor and send a `?`
   - The programs slots are listed, non is used
1. Open the debug monitor
   - The free memory is logged frequently
1. In the Serial Monitor,  send `{ 0 A: UK <Win>; W 2000; UT notepad; W 1000; UK <Enter>; W 1000; UT hello; } ` 
   - The program is repeated on the serial monitor and accepted with "thank you"
   - The created program steps are logged on the debug monitor
1. On the device, press the "A"-button
   - The program is executed, the notepad is opened and "hello" is written
1. Open the Windows Bluetooth setting and connect the device
1. In the Serial Monitor,  send `{ 3 E: BK <Win>; W 2000; BT notepad; W 1000; BK <Enter>; W 1000; BT hello; } ` 
    - The program is repeated on the serial monitor and accepted with "thank you"
    - The created program steps are logged on the debug monitor
1. On the device, set the mode to "3" press the "E"-button
    - The program is executed, the notepad is opened and "hello" is written
1. In the Serial Monitor,  send `{ P N: 1 1 0 1 3; } ` 
    - The pin is repeated on the serial monitor and accepted with "thank you"
    - On the debug monitor, "got pin" is logged.
1. On the device, set a wrong pin, set the mode to "0" and press the "A"-button
    - The status light is lit
    - On the debug monitor, "Wrong PIN" is logged
1. On the device, set the correct pin, set the mode to "0" and press the "A"-button
    - The program is executed, the notepad is opened and "hello" is written
1. End of the test
     - Disable the logging by changing the logging from `SoftwareSerial` to `FakeLogger`
     - Disconnect the device from Bluetooth

## 3.  Test PCB PARC

21. Connect the PC to the PCB PARC device, USB and Debug cable
1. In the Arduino IDE, open the project \Software\Src\PcbParcApp\PcbParcApp.ino 
1. Execute the test steps from "Test Parc"
1.. End of the test
    - Disable the logging by changing the logging from `SoftwareSerial` to `FakeLogger`
    - Disconnect the device from Bluetooth

## 4. Test UNO PARC

24. Connect the PC to the UNOPARC breadboard, USB and Debug cable
1. In the Arduino IDE, open the project \Software\Src\UnoParcApp\UnoParcApp.ino 
1. Upload the firmware
1. In the debug monitor, which is log output and terminal, send a `?`
    - The programs slots are listed, non is used
1. Start Atmel Flip
1. On the UNO, reset the Arduino Serial chip
1. In Flip, connect via USB
1. In Flip, load the Arduino-keyboard-0.3.hex to the UNO
1. In Flip, run the firmware update
1. Unplug and re-plug the Arduino UNO (the Arduino UNO is now acting as a USB keyboard)
1. In the debug monitor, send `{ 0 A: UK <Win>; W 2000; UK <Win>; } ` 
    - The program is repeated on the debug monitor and accepted with "thank you"
    - The created program steps are logged on the debug monitor
1. On the UNO PARC breadboard, press the "A"-button
    - The Windows opens for 2 seconds
1. End of the test
     - In Flip, revert the firmware (HEX file).

## 5. Test Simulator

37. Start the application 'WinParc.App.exe'
1. In the text field "Serial Monitor" send a `?`
    - The programs slots are listed, non is used
1. In the text field "Serial Monitor" send a `{ P N: 1 1 0 1 2; }`
    - The pin is repeated on the serial monitor and accepted with "thank you"
    - On the debug output, "got pin" is logged
1. In the text field "Serial Monitor" send a `{ 0 A: UT hello; }`
    - The program is repeated on the serial monitor and accepted with "thank you"
    - The created program step is logged on the debug monitor
1. Press the "A"-button
    - "Button press ignored." on the debug output
1. Set the code C4=true and press the "A"-button
    - "Wrong PIN, remaining retries: 2" on the debug output
    - Warn LED is "On" for 5 seconds
1. Set the code C4=true, C3=true, C1=true and press the "A"-button
    - "Execute { UT }" on the debug output
1. End of the test

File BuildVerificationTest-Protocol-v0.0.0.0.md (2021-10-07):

# Parc Build Verification Test Protocol

Date and Time: 

Build: 

Tester: 

| test item | passed status (passed/failed/skipped) | comment | accepted (yes/no) |
| --- | --- | --- | --- |
| PARC | | | |
| PCB PARC  | | | |
| UNO PARC  | | | |
| Simulator | | | |

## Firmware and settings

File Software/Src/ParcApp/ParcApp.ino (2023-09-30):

// Copyright (c) 2021-2023 Stefan Grimm. All rights reserved.
// Licensed under the LGPL. See LICENSE file in the project root for full license information.
//

#include <SoftwareSerial.h>
#include <Keyboard.h>
#include <TimerOne.h>

#include "ParcLib.h"
#include "Core/Messages.h"
#include "Core/KeypadAo.h"
#include "Core/HidAo.h"
#include "Core/TerminalAo.h"
#include "Core/SystemMonitorAo.h"

#include "Feather/HidBle.h"
#include "Feather/ProgramSteps.h"
#include "Feather/SystemHw.h"

#include "KeypadHw.h"
#include "Constants.h"

using namespace parc;
using namespace parclib;

void rtassert(bool condition) {
}

struct FakeLogger {
  FakeLogger(uint8_t a, uint8_t b) {}
  void begin(uint16_t a) {}
  template<class T>
  void print(T ch) {}
  template<class T>
  void print(T ch, uint8_t mode) {}
  template<class T>
  void println(T ch) {}
};
typedef FakeLogger Logger_t;  // SoftwareSerial, FakeLogger
Logger_t logger(Usb_ORA, Usb_YEL);
template<> Logger_t& Factory<Logger_t>::instance = logger;
typedef Factory<Logger_t> LoggerFac_t;

template<> Keyboard_& Factory<Keyboard_>::instance = Keyboard;
typedef Factory<Keyboard_> HidUsbFac_t;

typedef HidBle<LoggerFac_t> HidBle_t;
HidBle_t ble;
template<> HidBle_t& Factory<HidBle_t>::instance = ble;
typedef Factory<HidBle_t> HidBleFac_t;

SystemHw sysHw;
template<> SystemHw& Factory<SystemHw>::instance = sysHw;
typedef Factory<SystemHw> SystemHwFac_t;

Program<LoggerFac_t> programs[NumberOfPrograms];
Messages messages;

KeypadHw<LoggerFac_t> keypadHw;
KeypadAo<LoggerFac_t, KeypadHw<LoggerFac_t>> keypad(messages, keypadHw);

HidAo<LoggerFac_t, Program<LoggerFac_t>> hid(messages, programs);

SystemMonitorAo<LoggerFac_t, SystemHwFac_t, 216> systemMonitor(messages);

template<> bool CmdComparator<PsType::Wait>::equals(const char* another) const {
  return 'W' == another[0];
}
template<> bool CmdComparator<PsType::UsbKeycode>::equals(const char* another) const {
  return 'U' == another[0] && 'K' == another[1];
}
template<> bool CmdComparator<PsType::UsbText>::equals(const char* another) const {
  return 'U' == another[0] && 'T' == another[1];
}
template<> bool CmdComparator<PsType::BleKeycode>::equals(const char* another) const {
  return 'B' == another[0] && 'K' == another[1];
}
template<> bool CmdComparator<PsType::BleText>::equals(const char* another) const {
  return 'B' == another[0] && 'T' == another[1];
}
template<> bool CmdComparator<PsType::BleControlkey>::equals(const char* another) const {
  return 'B' == another[0] && 'C' == another[1];
}
template<> bool CmdComparator<CmdType::Pin>::equals(char** another) const {
  return 'P' == another[0][0] && 'N' == another[1][0];
}

// Has to filled in the order of the enum PsType, that is:
//  Wait, USB Keycode, USB Keycode repeated, USB Text, BLE Keycode, BLE Keycode repeated, BLE Text, BLE Control Key
typedef Typelist<ProgramStepWait<LoggerFac_t>,
                 Typelist<ProgramStepUsbKeyboardCode<LoggerFac_t, HidUsbFac_t>,
                          Typelist<ProgramStepUsbKeyboardCodeRepeated<LoggerFac_t, HidUsbFac_t>,
                                   Typelist<ProgramStepUsbKeyboardCodes<LoggerFac_t, HidUsbFac_t>,
                                            Typelist<ProgramStepUsbKeyboardText<LoggerFac_t, HidUsbFac_t>,
                                                     Typelist<ProgramStepBleKeyboardCode<LoggerFac_t, HidBleFac_t>,
                                                              Typelist<ProgramStepBleKeyboardCodeRepeated<LoggerFac_t, HidBleFac_t>,
                                                                       Typelist<ProgramStepBleKeyboardText<LoggerFac_t, HidBleFac_t>,
                                                                                Typelist<ProgramStepBleControlKey<LoggerFac_t, HidBleFac_t>,
                                                                                         NullType>>>>>>>>>
  ProgramStepList;

struct KnownKeycodes {
  static const uint8_t UsbRadix = 16;
  static const uint8_t UsbKeyCodeDel = 0xD4;
  static const uint8_t UsbKeyCodeTab = 0xB3;
  static const uint8_t UsbKeyCodeEnter = 0xB0;
  static const uint8_t UsbKeyCodeSpace = ' ';

  static const uint8_t BleRadix = 16;
  static const uint8_t BleKeyCodeDel = 0x4C;
  static const uint8_t BleKeyCodeTab = 0x2B;
  static const uint8_t BleKeyCodeEnter = 0x28;
  static const uint8_t BleKeyCodeSpace = 0x2C;
};

TerminalAo<ProgramStepList, Serial_, LoggerFac_t, HidBleFac_t, HidUsbFac_t, Program<LoggerFac_t>, SystemHwFac_t, KnownKeycodes, 30> terminal(Serial, messages, programs);

volatile bool tick_flag = false;
volatile bool fatalError = false;

void setup() {
  while (!Serial)
    ;

  Serial.begin(9600);
  logger.begin(9600);

  pinMode(LED_BUILTIN, OUTPUT);

  keypadHw.begin();
  keypadHw.pinMode<KeyPadSwitch::Btn_A>();
  keypadHw.pinMode<KeyPadSwitch::Btn_B>();
  keypadHw.pinMode<KeyPadSwitch::Btn_C>();
  keypadHw.pinMode<KeyPadSwitch::Btn_D>();
  keypadHw.pinMode<KeyPadSwitch::Btn_E>();
  keypadHw.pinMode<KeyPadSwitch::Sw_M0>();
  keypadHw.pinMode<KeyPadSwitch::Sw_M1>();
  keypadHw.pinMode<KeyPadSwitch::Code_1>();
  keypadHw.pinMode<KeyPadSwitch::Code_2>();
  keypadHw.pinMode<KeyPadSwitch::Code_3>();
  keypadHw.pinMode<KeyPadSwitch::Code_4>();

  ble.begin(false, false);
  Keyboard.begin();

  Timer1.initialize(1000L * TimerPeriod);
  Timer1.attachInterrupt(timer1InterruptHandler);
}

void loop() {
  rtassert(!fatalError);
  if (tick_flag) {

    keypad.load();
    hid.load();
    terminal.load();
    systemMonitor.load();

    keypad.run();
    hid.run();
    terminal.run();
    systemMonitor.run();

    tick_flag = false;
  }
}

void timer1InterruptHandler() {
  if (tick_flag == true) fatalError = true;
  tick_flag = true;
}

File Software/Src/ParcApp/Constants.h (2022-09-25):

// Copyright (c) 2021 Stefan Grimm. All rights reserved.
// Licensed under the LGPL. See LICENSE file in the project root for full license information.
//
#pragma once

namespace parc {

// Constants to avoids multiple usage of GPIOs.
// No additional memory is used because of the external constants.

// MCP expander pins
const uint8_t Pin_A = 7;
const uint8_t Pin_B = 6;
const uint8_t Pin_C = 5;
const uint8_t Pin_D = 4;
const uint8_t Pin_E = 0;
const uint8_t Pin_M0 = 1;
const uint8_t Pin_M1 = 2;

// Arduino pins
const uint8_t Pin_C1 = 10;
const uint8_t Pin_C2 = 9;
const uint8_t Pin_C3 = 6;
const uint8_t Pin_C4 = 5;

const uint8_t Usb_YEL = 11;
const uint8_t Usb_ORA = 12;

}

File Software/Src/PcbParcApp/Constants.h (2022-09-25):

// Copyright (c) 2021 Stefan Grimm. All rights reserved.
// Licensed under the LGPL. See LICENSE file in the project root for full license information.
//
#pragma once

namespace pcbparc {

// Constants to avoids multiple usage of GPIOs.
// No additional memory is used because of the external constants.

// MCP expander pins
const uint8_t Pin_E = 0;
const uint8_t Pin_C1 = 1;
const uint8_t Pin_C2 = 2;
const uint8_t Pin_C3 = 3;
const uint8_t Pin_C4 = 4;
const uint8_t Pin_M0 = 6;
const uint8_t Pin_M1 = 7;

// Arduino pins
const uint8_t Pin_A = 6;
const uint8_t Pin_B = 9;
const uint8_t Pin_C = 5;
const uint8_t Pin_D = 10;

const uint8_t Usb_YEL = 11;
const uint8_t Usb_ORA = 12;

}

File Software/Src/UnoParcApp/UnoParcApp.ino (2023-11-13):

// Copyright (c) 2021-2023 Stefan Grimm. All rights reserved.
// Licensed under the LGPL. See LICENSE file in the project root for full license information.
//

#include <SoftwareSerial.h>
#include <TimerOne.h>

#include "ParcLib.h"
#include "Core/Messages.h"
#include "Core/KeypadAo.h"
#include "Core/HidAo.h"
#include "Core/TerminalAo.h"
#include "Core/SystemMonitorAo.h"

#include "Feather/SystemHw.h"

#include "UnoBreadboard.h"
#include "Constants.h"
#include "ProgramSteps.h"

using namespace unoparc;

void rtassert(bool condition) {
}

typedef SoftwareSerial TerminalConsole_t;
TerminalConsole_t terminalConsole(Usb_ORA, Usb_YEL);

struct FakeLogger {
  FakeLogger(uint8_t a, uint8_t b) {}
  void begin(uint16_t a) {}
  template<typename T>
  void print(T ch) {}
  template<typename T>
  void print(T ch, uint8_t mode) {}
  template<typename T>
  void println(T ch) {}
  template<typename T>
  void println(T ch, uint8_t mode) {}
  void println() {}
};
FakeLogger logger(Usb_ORA, Usb_YEL);
template<> FakeLogger& Factory<FakeLogger>::instance = logger;
typedef Factory<FakeLogger> LoggerFac_t;  // TerminalConsole_t, FakeLogger

template<> HardwareSerial& Factory<HardwareSerial>::instance = Serial;
typedef Factory<HardwareSerial> HidUsbFac_t;

NullType ble;
template<> NullType& Factory<NullType>::instance = ble;
typedef Factory<NullType> HidBleFac_t;

SystemHw sysHw;
template<> SystemHw& Factory<SystemHw>::instance = sysHw;
typedef Factory<SystemHw> SystemHwFac_t;

typedef UnoBreadboard<LoggerFac_t> Keypad_t;
Keypad_t keypadHw;

Program<LoggerFac_t> programs[NumberOfPrograms];
Messages messages;

KeypadAo<LoggerFac_t, Keypad_t> keypad(messages, keypadHw);
HidAo<LoggerFac_t, Program<LoggerFac_t>> hid(messages, programs);

SystemMonitorAo<LoggerFac_t, SystemHwFac_t, 216> systemMonitor(messages);

template<> bool CmdComparator<PsType::Wait>::equals(const char* another) const {
  return 'W' == another[0];
}
template<> bool CmdComparator<PsType::UsbKeycode>::equals(const char* another) const {
  return 'U' == another[0] && 'K' == another[1];
}

struct ProgramStepFake : public ProgramStep<LoggerFac_t> {
  ProgramStepFake(KeyCode keyCode)
    : ProgramStep(0) {}
  ProgramStepFake(KeyCode keyCode, uint8_t repetitions)
    : ProgramStep(0) {}
  ProgramStepFake(const char* text)
    : ProgramStep<LoggerFac_t>(0) {}
  ProgramStepFake(KeyCode keyCode, char secondKey)
    : ProgramStep<LoggerFac_t>(0) {}
  void action(VirtualAction type, uint8_t& tick) override{};
};

// Has to filled in the order of the enum PsType, that is:
//  Wait, USB Keycode, USB Keycode repeated, USB Keycodes, USB Text, BLE Keycode, BLE Keycode repeated, BLE Text, BLE Control Key
typedef Typelist<ProgramStepWait<LoggerFac_t>,
                 Typelist<ProgramStepUsbKeyboardCode<LoggerFac_t, HidUsbFac_t>,
                          Typelist<ProgramStepFake,
                                   Typelist<ProgramStepFake,
                                            Typelist<ProgramStepFake,
                                                     Typelist<ProgramStepFake,
                                                              Typelist<ProgramStepFake,
                                                                       Typelist<ProgramStepFake,
                                                                                Typelist<ProgramStepFake,
                                                                                         NullType>>>>>>>>>
  ProgramStepList;

struct KnownKeycodes {
  static const uint8_t UsbRadix = 10;
  static const uint8_t UsbKeyCodeDel = 76;    // 0x4C
  static const uint8_t UsbKeyCodeTab = 43;    // 0x2B
  static const uint8_t UsbKeyCodeEnter = 40;  // 0x28
  static const uint8_t UsbKeyCodeSpace = 44;  // 0x2C

  static const uint8_t BleRadix = 0;
  static const uint8_t BleKeyCodeDel = 0;
  static const uint8_t BleKeyCodeTab = 0;
  static const uint8_t BleKeyCodeEnter = 0;
  static const uint8_t BleKeyCodeSpace = 0;
};

TerminalAo<ProgramStepList, TerminalConsole_t, LoggerFac_t, HidBleFac_t, HidUsbFac_t, Program<LoggerFac_t>, SystemHwFac_t, KnownKeycodes, 30> terminal(terminalConsole, messages, programs);

volatile bool tick_flag = false;
volatile bool fatalError = false;

void setup() {
  while (!Serial)
    ;

  Serial.begin(9600);
  terminalConsole.begin(9600);

  pinMode(LED_BUILTIN, OUTPUT);

  keypadHw.pinMode<KeyPadSwitch::Btn_A>();
  keypadHw.pinMode<KeyPadSwitch::Btn_B>();
  keypadHw.pinMode<KeyPadSwitch::Btn_C>();
  keypadHw.pinMode<KeyPadSwitch::Btn_D>();
  keypadHw.pinMode<KeyPadSwitch::Btn_E>();
  keypadHw.pinMode<KeyPadSwitch::Sw_M0>();

  Timer1.initialize(1000L * TimerPeriod);
  Timer1.attachInterrupt(timer1InterruptHandler);
}

void loop() {
  rtassert(!fatalError);
  if (tick_flag) {
    keypad.load();
    hid.load();
    terminal.load();
    systemMonitor.load();

    keypad.run();
    hid.run();
    terminal.run();
    systemMonitor.run();

    tick_flag = false;
  }
}

void timer1InterruptHandler() {
  if (tick_flag == true) fatalError = true;
  tick_flag = true;
}

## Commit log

2021-02-14 Initial check-in.
    [Keypad-v2.fzz, Parc-Case.skp, Parc-Top.skp]
2021-02-15 Correct soldering scheme keypad.
2021-02-15 Add Fritzing project.
    [Keypad.fzz]
2021-02-22 Update sketchup models.
    [Parc-Case.skp, Parc-Top.skp, Parc-Total.skp]
2021-03-07 Add project UnoParcApp. Make changes to make PIN optional and key codes platform dependant.
2021-03-07 Production ready keypad V2 Rev1
    [Keypad-v2.fzz]
2021-03-07 Fix Pin Comparator.
2021-03-11 Replace term "profile" with "mode".
    [KeypadAo.h]
2021-03-14 Add new programsteps usb- and ble-code repeated. Add PcbParcApp and PcbKeypadTest. Fix split function.
    [BluefruitConfig.h, Constants.h, KeypadAo.h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]
2021-03-15 Add workaround for MCP-library bug and only read mode/code when a button is pressed.
    [KeypadAo.h, KeypadHw.h]
2021-03-15 Read MCP only every 100 ms in ParcApp and PcbParcApp.
2021-03-18 Add Sketchup models for PcbParc.
    [PcbParc-Case.skp, PcbParc-Shield.skp, PcbParc-Top.skp]
2021-03-20 Increase the command buffer size to 30. BleKeyboard to progmem Remove unused code Fix HidAo for programs with length > 255 Improve logs in TerminalAo Memory waring at 160 bytes
    [KeypadAo.h, ParcApp.ino, PcbParcApp.ino]
2021-03-21 Memory optimizations. Tick as program member and not per step-object. Low memory as template parameter. Replace typename with class Add software design document (work in progress).
    [KeypadHw.h, ParcApp.ino, PcbParcApp.ino]
2021-04-10 - Rename MemoryMonitorAo in SystemMonitorAo - Rename Registers - Add infrastructure class SystemHw - Fix idle state in HidAo - Update unit tests - Corrections in documents
    [KeypadAo.h, ParcApp.ino, PcbParcApp.ino]
2021-04-17 - Move Documents into the Wiki - Add description files for the ParcLib - Use FakeLogger in PcbParcApp - Add a first version of the build instructions - Remove unused project from WinParc
    [Parc-Case.stl, Parc-Top.stl, PcbParc-Case.stl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]
2021-04-28 - Add PcbParc project, Gerber and Fitzing - Add keypad test projects - Remove the openings for the shield in the pcb case - instructuables.md as on instructables.com
    [Keypad-v2.fzz, PcbParc-Case.skp, PcbParc-Case.stl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]
2021-05-24 Squashed commit of the following:
    commit 30271252eb678eb755c8bfc019bb10bd3cdf3ad1
    Author: mrstefangrimm <motionsystems@grimm.com>
    Date: Mon May 24 14:08:36 2021 +0200
    Update Readme.
    commit 605a377b48d6444081f4babdc78d26bc4b9d0e86
    Author: mrstefangrimm <motionsystems@grimm.com>
    Date: Mon May 24 13:57:47 2021 +0200
    Update build instructions.
    commit cbc8f7326533911cd837d0f6dbc2ac1f479004e3
    Author: mrstefangrimm <motionsystems@grimm.com>
    Date: Mon May 24 13:33:54 2021 +0200
    Fix the hardware pins for UnoParc.
    commit 34743e69b106207dab68b9184590687e55669a3d
    Author: mrstefangrimm <motionsystems@grimm.com>
    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
    [HidAoTest.ino, KeypadAo.h, KeypadHw.h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]
2021-06-06 Squashed commit of the following:
    commit dcab254d43078ae7b3b029a298cad116fcb74ebc
    Date: Sun Jun 6 18:10:57 2021 +0200
    Add file for the instructable "Programmable Arduion Remote Control (PCB)"
    commit 021efeb8f4939033456060be7b97bc6a845d48fa
    Date: Sun Jun 6 18:09:51 2021 +0200
    Add files for the instructable "Programmable Arduino Remote Control (PCB).
    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
    [Keypad-Uno.fzz, Keypad-v2.fzz]
2021-10-05 Call print instead println for the command UT.
2021-10-07 Change interface FakeUsbKeyboard from println to print
2022-09-23 Change from MCP23008 to MCP23017 Arduino Library.
2022-09-25 Change from .NET Framework 4.8 to 4.8.1.
2023-09-19 Update unit tests to be BDD-like (#5)
    * Replaces TestMacros.h with NotquiteBDD.h.
    * Uses StandardCplusplus in the unit tests.
    ---------
    [HidAoTest.ino, ProgramTest.ino, StringParcTest.ino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]
2023-09-30 Change registers into queues (#6)
    * Replaces register array with Register class (work in progress). Adds BitTimer.
    * Moves BitTimer to separate file. Replaces keypad register with timer. Replaces terminal register with timer.
    * Replaces KEYPAD_MONITOR_WRONGPIN with KEYPAD_MONITOR_PIN.
    * Replaces MONITOR_MONITOR_TIMEOUT with timer.
    * Replaces checkRegisters() with load() and run().
    * Uses timer increment in load and timer current in run.
    * Changes BitTimer argument to countDown.
    * Adds ValueQueue.
    * Adds Timer1 and timer interrupt that triggers the tasks.
    * Adds unit test.
    * Renames registers to messages.
    * Updates drawings.
    ---------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
    [BitTimerTest.ino, KeypadAo.h, KeypadAoTest.ino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]
2023-09-30 Replaces Registers.h with Messages.h. Adds rtassert function. (#8)
    [HidAoTest.ino, KeypadAoTest.ino, ParcApp.ino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]
2023-10-01 Resolve compiler warnings (#9)
    * Pre-compiler warning.
    * Removes unused arguments.
    * Adds default member initializer.
    * Explicit constructors.
    * Changes link to StandardCplusplus
    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
    [ProgramTest.ino]
2023-11-13 In TerminalAo, replace enum with statemachine (#10)
    * Makes use of tsm in TerminalAo.
    * Updates compile-sketches.yml
    * Updates TerminalAo statemachine and unit tests.
    * Renames BitTimer to BitCounter.
    * Updates git workflow yml
    * Updates instruction markdowns.
    * Changes unit test release optimizations.
    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
    [BitCounterTest.ino, KeypadAo.h]
